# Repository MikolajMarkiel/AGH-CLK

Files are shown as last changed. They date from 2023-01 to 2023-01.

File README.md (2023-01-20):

# AGH-CLK
Tiny project of embedded wristwatch based on STM32 realised for University - course Design-Laboratory

## Project assumptions
The main goal was to make self-contained embedded wristwatch module that could be used with dedicated wrist as a complete wristwatch

## Technical specification
-	LCD screen 240x240 1,3 inches
-	Clock precision: -6 sec/day (would be better with capacitor corrections)
-	Current consumption: 54,5 mA (without sleep feature)
-	Estimated lifetime per cycle – around 9h (would be better with implemented sleep feature)
-	Charging: 5 VDC; 400 mA; around 75 minutes to full charge battery 500mAh 

## Overview
This project has been designed for purpose of learning STM32 programming and designing PCB with KiCad software. It won't be supported or improved in future. 
There are many mistakes such as huge current consumption, clock precision or aliased display. It could be of course improved for example by adding sleep feature, but it is not necessary to do right now, because others projects also wait to be designed. 

For more information about the project lets read AGH-CLK-Design_Process_Specification inside "Documentation" folder.

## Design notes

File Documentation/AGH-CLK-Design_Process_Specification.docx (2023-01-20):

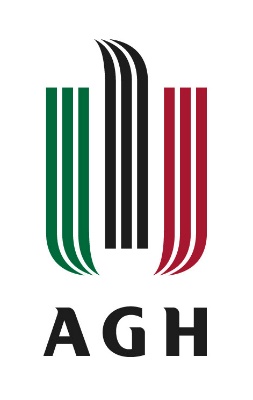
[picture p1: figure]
Wersje barwne znaku / Akademia Górniczo-Hutnicza w Krakowie

Design Laboratory

Project of Embedded wristwatch module powered by li-pol cell

AGH-CLK

Mateusz Bik, Mikołaj Markiel, Piotr Mosurek

20.01.2023

# Contents page

# 1. Design assumptions

## 1.1. Project description

The main goal was to make self-contained embedded wristwatch module that could be used with dedicated wrist as a complete wristwatch. That device has his own power supply made by li-pol cell with dedicated hardware driver. As a display full color LCD screen module is used with 240x240px and ST7789 driver. Device will be controlled by microprocessor STM32L051K6T6 that is placed on a dedicated printed circuit board “AGH-CLK-01” with the rest of peripherals.

## 1.2. Block diagram

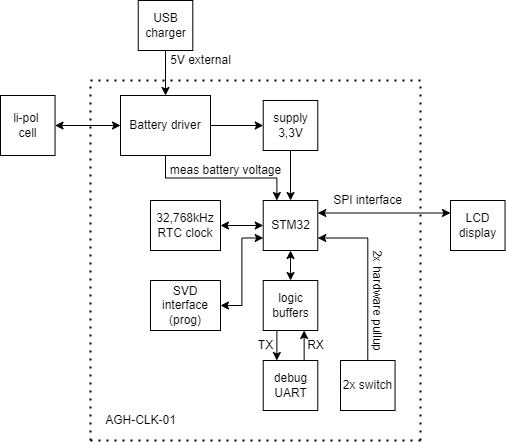
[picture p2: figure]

## 1.3. Technical specification:

- LCD screen 240x240 1,3 inches
- Clock precision: -6 sec/day (would be better with capacitor corrections)
- Current consumption: 54,5 mA (without sleep feature)
- Estimated lifetime per cycle – around 9h (would be better with implemented sleep feature)
- Charging: 5 VDC; 400 mA; around 75 minutes to full charge battery 500mAh

# 2. Schematic and layout descriptions

Schematic and layout was designed in KiCad Version: (6.0.9). PCB was prepared by JLCPCB company based on gerber files generated by KiCad.

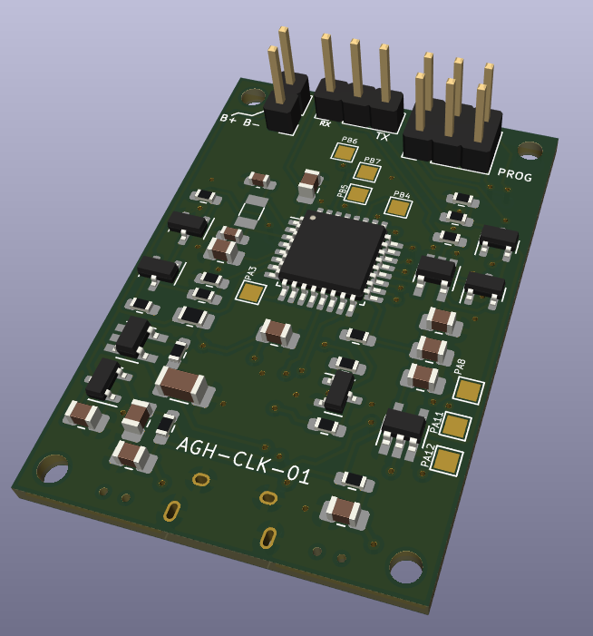
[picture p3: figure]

## 2.1. AGH-CLK-01 schematic

Full documentation is available in https://github.com/MikolajMarkiel/AGH-CLK

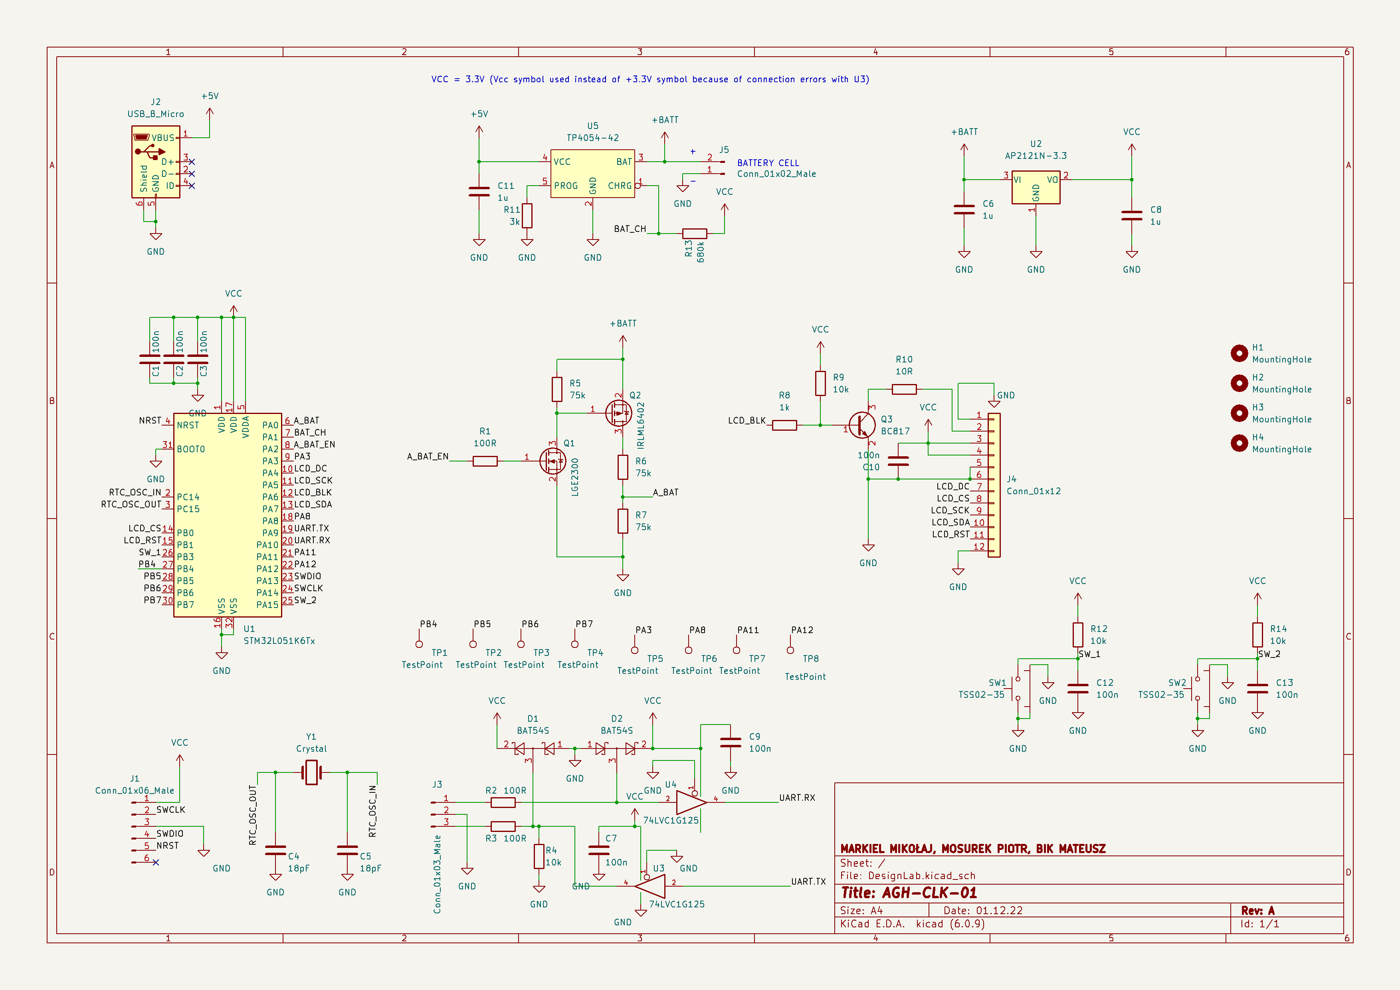
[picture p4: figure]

## 2.2. AGH-CLK-01 layout design

Full documentation is available in https://github.com/MikolajMarkiel/AGH-CLK

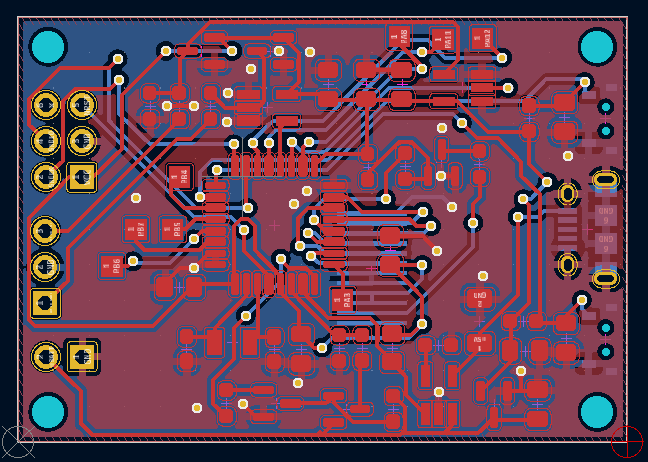
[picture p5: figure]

## 2.3. AGH-CLK-01 Bill of materials

Ref | Qnty | Value | Footprint | Description
C1, C2, C3, C7, C9, C10, C12, C13, | 8 | 100n | Capacitor_SMD:C_0805_2012Metric_Pad1.18x1.45mm_HandSolder | Unpolarized capacitor
C4, C5, | 2 | 18pF | Capacitor_SMD:C_0603_1608Metric_Pad1.08x0.95mm_HandSolder | Unpolarized capacitor
C6, C8, | 2 | 1u | Capacitor_SMD:C_0805_2012Metric_Pad1.18x1.45mm_HandSolder | Unpolarized capacitor
C11, | 1 | 1u | Capacitor_SMD:C_1206_3216Metric_Pad1.33x1.80mm_HandSolder | Unpolarized capacitor
D1, D2, | 2 | BAT54S | Package_TO_SOT_SMD:SOT-23 | schottky barrier diode
H1, H2, H3, H4, | 4 | MountingHole | MountingHole:MountingHole_2.2mm_M2_ISO7380 | Mounting Hole without connection
J1, | 1 | Conn_01x06_Male | Connector_PinHeader_2.54mm:PinHeader_2x03_P2.54mm_Vertical | Generic connector, single row, 01x06, script generated (kicad-library-utils/schlib/autogen/connector/)
J2, | 1 | USB_B_Micro | Connector_USB:USB_Micro-B_Amphenol_10118194_Horizontal | USB Micro Type B connector
J3, | 1 | Conn_01x03_Male | Connector_PinHeader_2.54mm:PinHeader_1x03_P2.54mm_Vertical | Generic connector, single row, 01x03, script generated (kicad-library-utils/schlib/autogen/connector/)
J4, | 1 | Conn_01x12 | Connector:Flex_Tape_12x0.635 | Generic connector, single row, 01x12, script generated (kicad-library-utils/schlib/autogen/connector/)
J5, | 1 | Conn_01x02_Male | Connector_PinHeader_2.54mm:PinHeader_1x02_P2.54mm_Vertical | Generic connector, single row, 01x02, script generated (kicad-library-utils/schlib/autogen/connector/)
Q1, | 1 | LGE2300 | Package_TO_SOT_SMD:SOT-23 | 1.2A Id, 60V Vds, 480mOhm Rds, N-Channel HEXFET Power MOSFET, SOT-23
Q2, | 1 | IRLML6402 | Package_TO_SOT_SMD:SOT-23 | -3.7A Id, -20V Vds, 65mOhm Rds, P-Channel HEXFET Power MOSFET, SOT-23
Q3, | 1 | BC817 | Package_TO_SOT_SMD:SOT-23 | 0.8A Ic, 45V Vce, NPN Transistor, SOT-23
R1, R2, R3, | 3 | 100R | Resistor_SMD:R_0603_1608Metric_Pad0.98x0.95mm_HandSolder | Resistor
R4, R9, R12, R14, | 4 | 10k | Resistor_SMD:R_0603_1608Metric_Pad0.98x0.95mm_HandSolder | Resistor
R5, R6, R7, | 3 | 75k | Resistor_SMD:R_0603_1608Metric_Pad0.98x0.95mm_HandSolder | Resistor
R8, | 1 | 1k | Resistor_SMD:R_0603_1608Metric_Pad0.98x0.95mm_HandSolder | Resistor
R10, | 1 | 10R | Resistor_SMD:R_0603_1608Metric_Pad0.98x0.95mm_HandSolder | Resistor
R11, | 1 | 3k | Resistor_SMD:R_0603_1608Metric_Pad0.98x0.95mm_HandSolder | Resistor
R13, | 1 | 680k | Resistor_SMD:R_0815_2038Metric_Pad1.20x4.05mm_HandSolder | Resistor
SW1, SW2, | 2 | TSS02-35 | Button_Switch_SMD:SW_SPST_TSS02-035NT | Push button switch, generic, two pins
TP1, TP2, TP3, TP4, TP5, TP6, TP7, TP8, | 8 | TestPoint | TestPoint:TestPoint_Pad_1.5x1.5mm | test point
U1, | 1 | STM32L051K6Tx | Package_QFP:LQFP-32_7x7mm_P0.8mm | ARM Cortex-M0+ MCU, 32KB flash, 8KB RAM, 32MHz, 1.65-3.6V, 25 GPIO, LQFP-32
U2, | 1 | AP2121N-3.3 | Package_TO_SOT_SMD:SOT-23 | 300mA low dropout linear regulator, shutdown pin, 2.5V-6V input voltage, 3.3V fixed positive output, SOT-23 package
U3, U4, | 2 | 74LVC1G125 | Package_TO_SOT_SMD:SOT-23-5_HandSoldering | Single Buffer Gate Tri-State, Low-Voltage CMOS
U5, | 1 | TP4054-42 | Package_TO_SOT_SMD:SOT-23-5_HandSoldering
Y1, | 1 | Crystal | Crystal:Crystal_SMD_3215-2Pin_3.2x1.5mm | Two pin crystal

## 2.4. Battery Driver block

For controlled battery charging TP4054-42 driver has been used. Maximum charging current of this driver is up to 1200mA. The particular value of the maximum current is configured by RPROG connected to PROG pin of driver The RPROG value is calculated by formula:

I_(BAT) =(V_(PROG))/(R_(PROG))*1200 (V_(PROG) =1V)

For purpose of this device assumed that the charging current should be around 400mA. The calculated RPROG value should be then no more than 3kΩ. The 3kΩ value has been chosen.

According to documentation weak pull-up should be used for checking battery charging state and connected to CHRG pin and to processor as input.

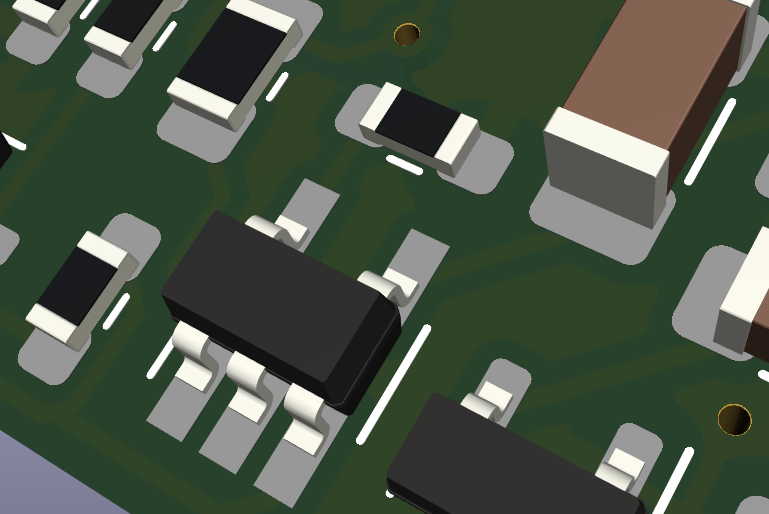
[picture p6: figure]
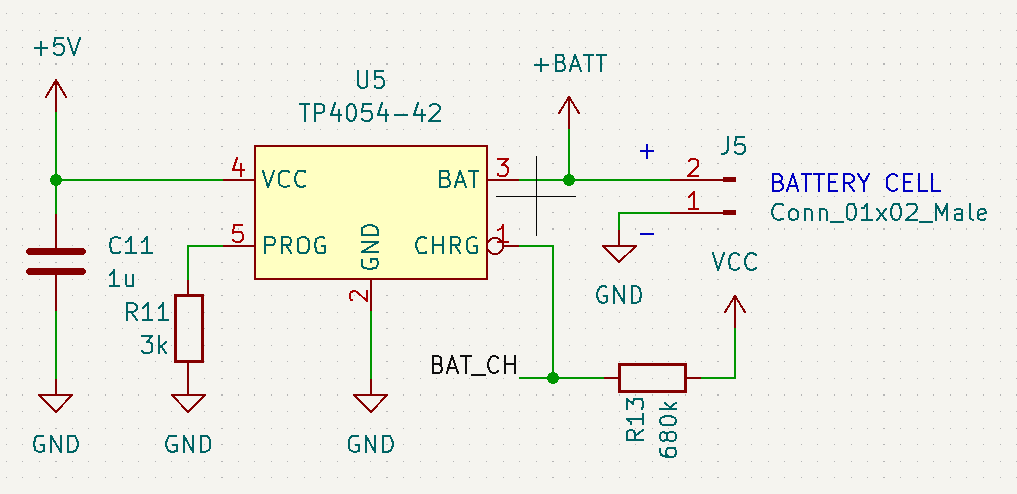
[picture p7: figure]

## 2.5. Power supply block

The voltage from battery is dropped to 3,3V for purpose of supplying processor and other peripherals. It is done by AP2127-3.3 linear voltage regulator. According to documentation this regulator has 2% accuracy, so the voltage should fit in 3,267-3,333V. The measured voltage is 3,291V, so the value is correct.

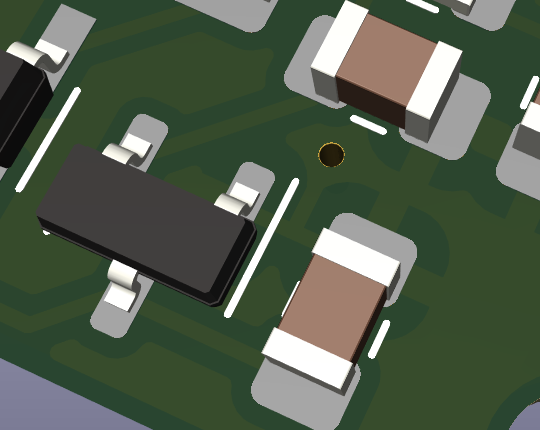
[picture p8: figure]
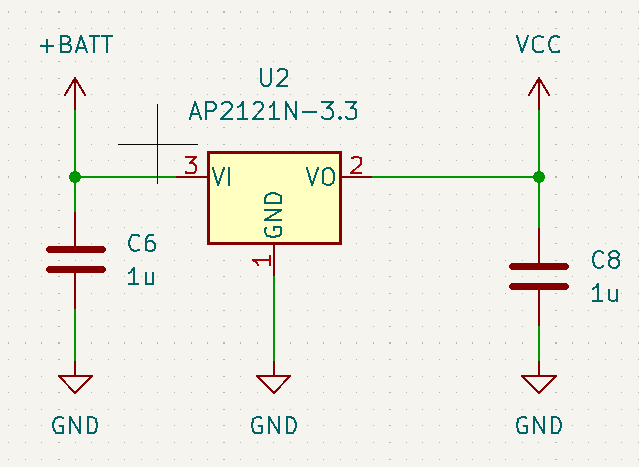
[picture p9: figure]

## 2.6. RTC clock

The STM32L051K6T6 supports external RTC crystal for precise counting. Because of that a ABS07-32.768KHZ-T crystal is used. It has 12.5pF load capacitance (CL). There is necessary to add extra capacitance for both terminals that aggregately should be equal to CL of crystal. We should also predict capacitance of copper paths for calculations (CSTRAY) (usually 2-5pF):

C_L =(C_(X1) *C_(X2))/(C_(X1) +C_(X2))+C_(STRAY)

We needed to use the same capacitor for this purpose, so the capacitance should then be in range 15-21pF. The correction of capacitance values of this circuit should be verified after assembly by checking clock precision.

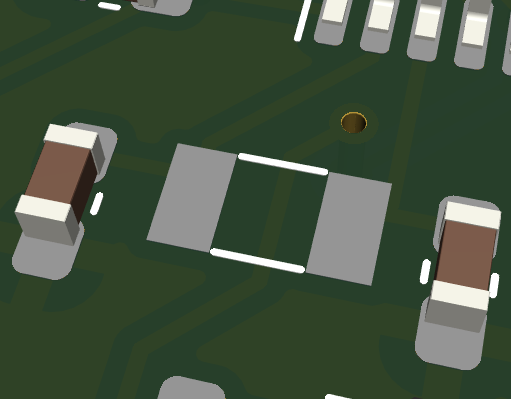
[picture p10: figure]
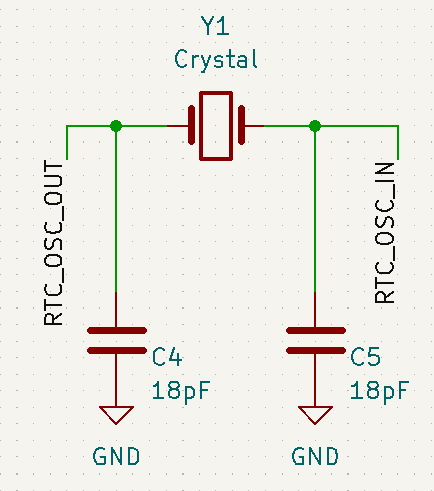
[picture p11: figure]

## 2.7. Processor and programming block

This project hasn’t had demanding requirements, so cheap STM32 processor would be enough to fulfil them all. We’ve decided to use STM32L051K6T6 processor. It has all necessary features and peripherals like SPI communication for LCD screen and RTC based on external clock.

To protect processor from unwanted resetting device we’ve placed 100nF decoupling capacitors near every power supply pin.

Programming will be realized by SWD interface. Unfortunately, this processor doesn’t have SWO pin, so real time debugging will be realized by UART.

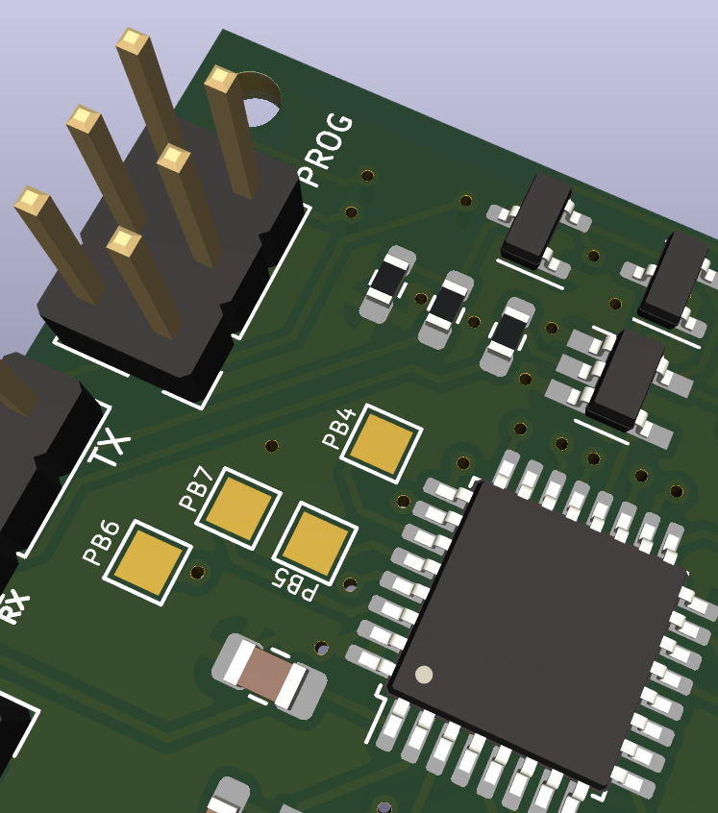
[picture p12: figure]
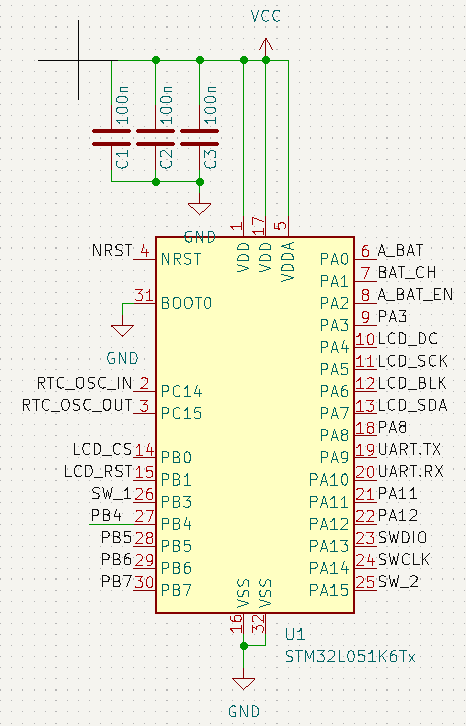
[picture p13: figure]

## 2.8. Debug Block

For real time debugging and testing UART communication has been carried to goldpin headers. To protect pins from dangerous signal RXD and TXD pins are buffered and protected from overvoltage.
Unfortunately this feature was not necessary to implement in software, and thus wasn’t tested.

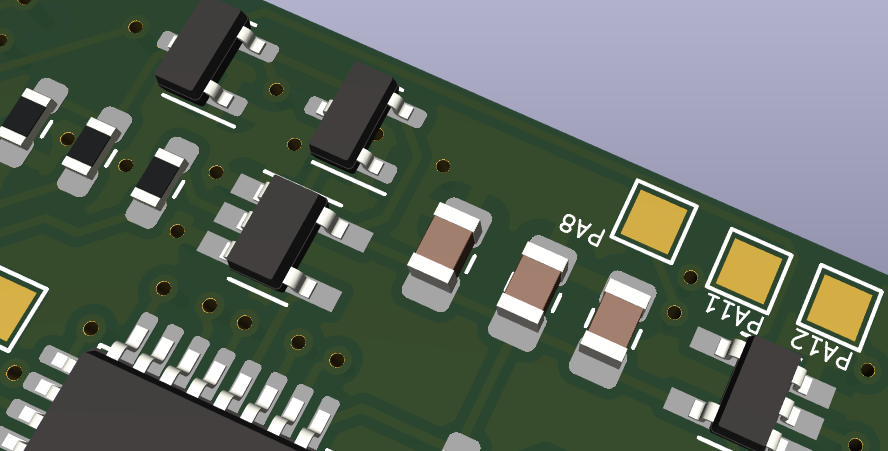
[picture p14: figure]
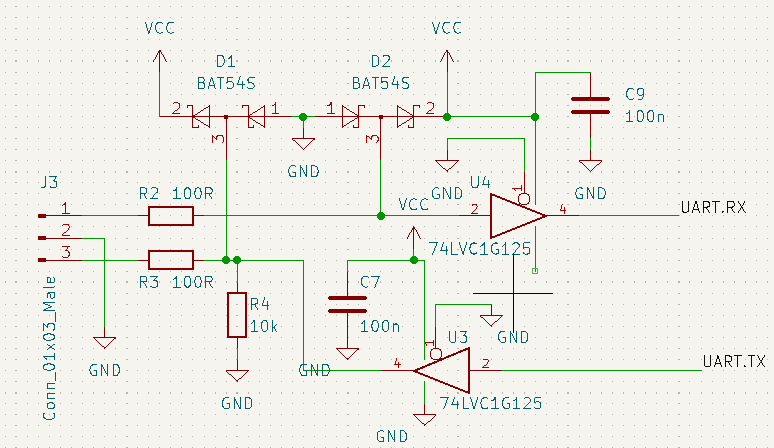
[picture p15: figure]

## 2.9. Keyboard

To control device, we’ve added two switches „<” and „>”. They will be used for setting actual time and date feature. To prevent from bouncing effect, we’ve used 100nF capacitor that filter unwanted noise:

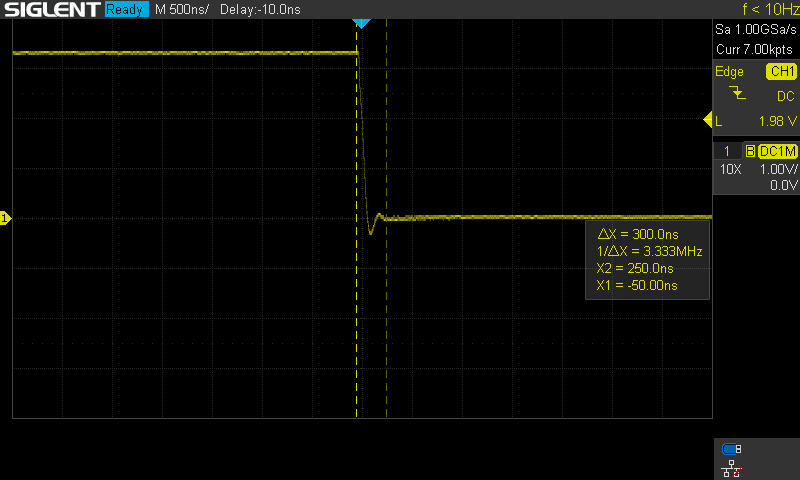
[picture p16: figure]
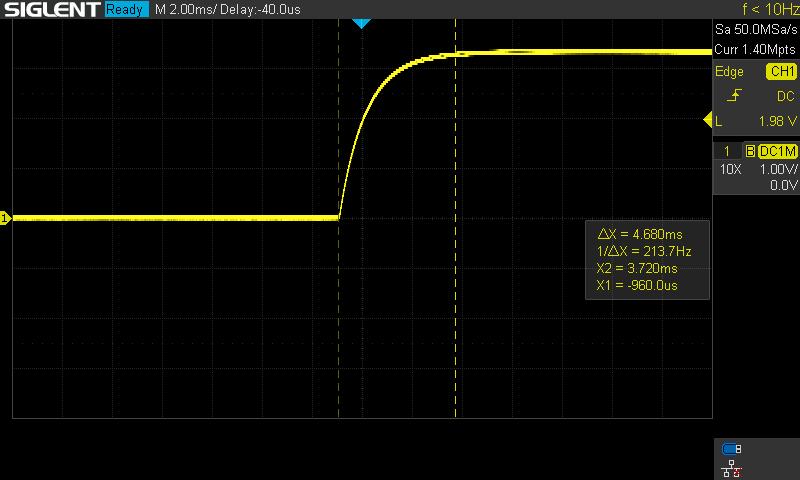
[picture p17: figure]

Figure 1: Removing bouncing effect from switches. At the left switch is pressed and pulled to ground, at the right switch is released and capacitor is charging again. The probe was connected directly to processor pin.

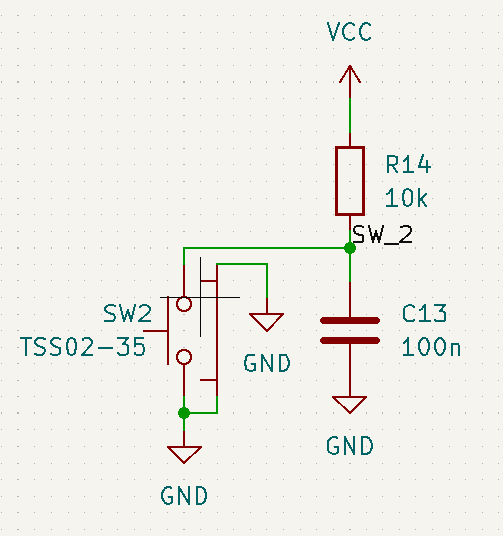
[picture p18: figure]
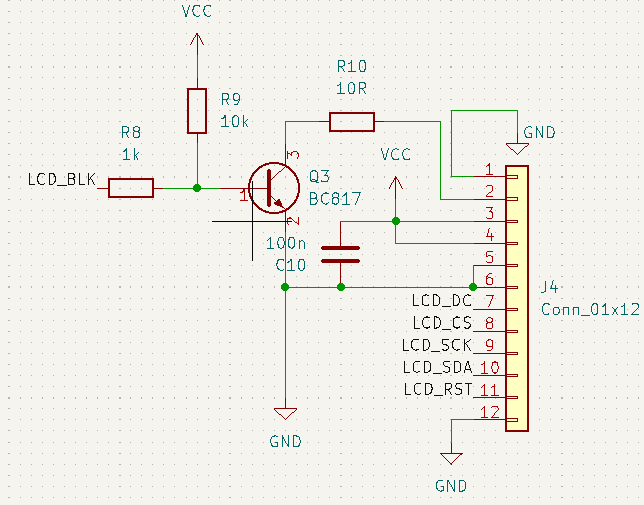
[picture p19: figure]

## 2.10. Display block

LCD screen display is communicating with processor via SPI half-duplex interface. The baud rate is 16 MBits/s. To unload processor from long transmission cycle data is transferred by DMA feature. There is also predicted possibility to control backlight of LCD screen.

# 3. Software description

## 3.1. Environment:

Software environment: STM32CubeIDE; Version: 1.10.1; Build: 12716_20220707_0928 (UTC)
Programmer: The ST-LINK/V2-1 programming and debugging tool integrated with NUCLEO-L476RG board

## 3.2. Code:

Full code is available in https://github.com/MikolajMarkiel/AGH-CLK

Libraries we’ve used in project:

- ST7789 driver with UGUI: https://github.com/deividAlfa/ST7789-STM32-uGUI

## 3.3. Performance algorithm

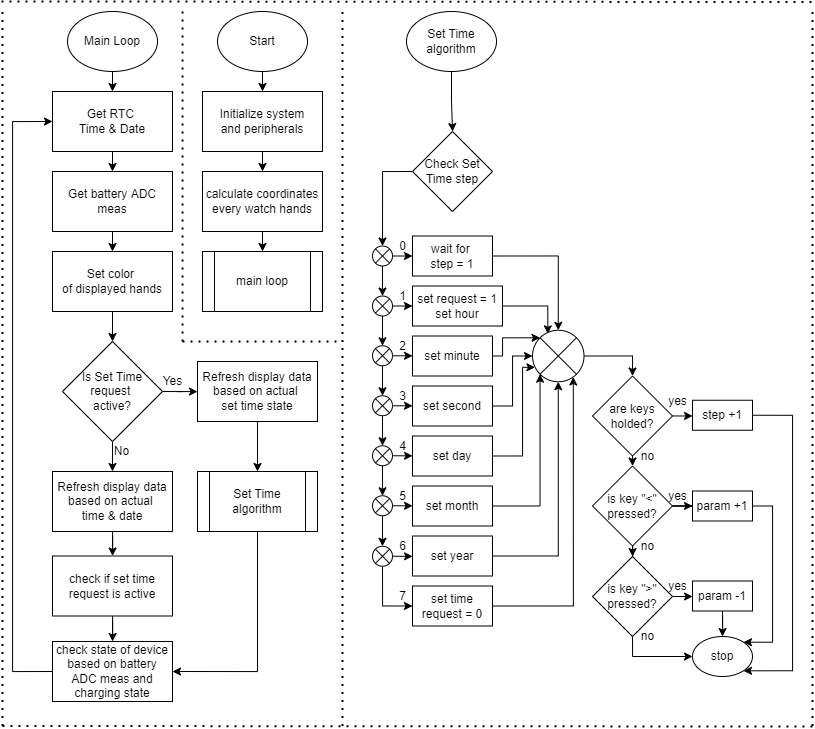
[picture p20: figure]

# 4. Performance tests

## 4.1. Battery performance

All tests were performed on a li-pol cell 2650mAh 3,7V.

Charging cycle:

Discharging cycle:

## 4.2. Clock precision

The test consist in synchronizing the clock and read its state after 24 hours. It was performed only once.

- Test 1: 18.01.23 18:50:00 – synchronize clock
- Test 2: 19.01.23 18:50:00 – read value 18:49:54 - 6s delay/day.

# 5. Future improvements and fixes

- Sleep feature – to decrease battery consumption and protect battery from over discharging.
- RTC capacitors update – for better clock precision.
- Touch pad – to allow controlling more features.
- UART-USB driver – to allow programming and debug via USB.
- Wristwatch case – to make this device wearable.

Version 1.020.01.2023Page 1 of 2

Design Laboratory AGH-CLK Project of Embedded wristwatch module powered by li-pol cell Opracował: Mikołaj Markiel, Mateusz Bik, Piotr Mosurek

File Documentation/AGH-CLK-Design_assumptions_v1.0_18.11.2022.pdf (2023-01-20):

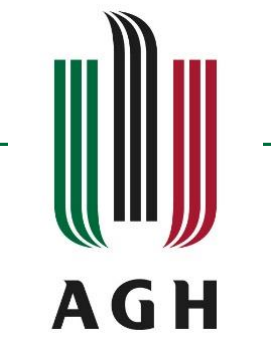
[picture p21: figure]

### Mateusz Bik, Mikołaj Markiel, Piotr Mosurek

18.11.2022

# Design Laboratory

# Project of Embedded wristwatch module powered by li-pol cell

## AGH-CLK

Design Laboratory | AGH-CLK
Project of Embedded wristwatch module powered by li-pol cell | Opracował: Mikołaj Markiel
Wersja 1.0 | 18.11.2022 | Strona 1 z 3

### Contents page


Wersja 1.0 | 18.11.2022 | Strona 2 z 3

### 1. Design assumptions

### 1.1. Project description

The main goal is to make self-contained embedded wristwatch module that could be used with dedicated wrist as a complete wristwatch. That device will have his own supply made by li-pol cell with dedicated hardware driver. As a display will be used full color LCD screen module with 240x240px and ST7789 driver. Device will be controlled by microprocessor STM32 (particular type will be pick in time) that would be placed on a dedicated printed circuit board “AGH-CLK-01” with the rest of peripherals. Everything should be assembled as a ready-to-use device.

### 1.2. Block diagram

### 1.3. Labour distribution

- Mateusz Bik:
- AGH-CLK-01 hardware schematic design
- Necessary schematic simulations
- Piotr Mosurek:
- AGH-CLK-01 hardware layout design
- Preparing bill of materials
- Collecting parts and device montage
- Mikołaj Markiel:
- AGH-CLK-01 software design
- Functional tests, debug and improvements

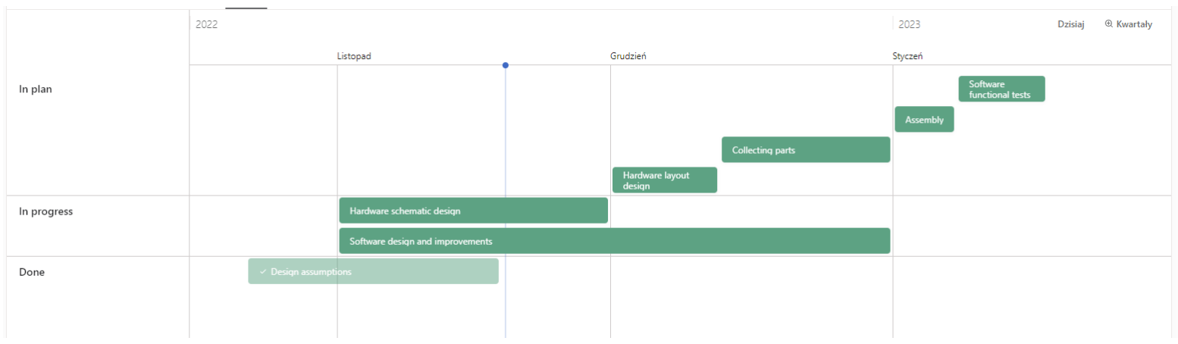
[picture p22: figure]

Wersja 1.0 | 18.11.2022 | Strona 3 z 3

### 2. Project schedule

Figure 1 Project schedule has been made in Asana

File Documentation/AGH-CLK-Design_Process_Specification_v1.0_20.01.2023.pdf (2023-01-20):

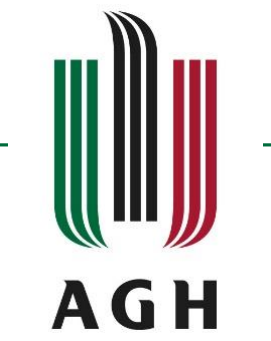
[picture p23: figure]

### Mateusz Bik, Mikołaj Markiel, Piotr Mosurek

# Design Laboratory

# Project of Embedded wristwatch module powered by li-pol cell

## AGH-CLK

Design Laboratory | AGH-CLK
Project of Embedded wristwatch module powered by li-pol cell | Opracował: Mikołaj Markiel, Mateusz Bik, Piotr Mosurek
Version 1.0 | 20.01.2023 | Page 1 of 11

20.01.2023

### Contents page

### 1. Design assumptions

### 1.1. Project description

The main goal was to make self-contained embedded wristwatch module that could be used with dedicated wrist as a complete wristwatch. That device has his own power supply made by li-pol cell with dedicated hardware driver. As a display full color LCD screen module is used with 240x240px and ST7789 driver. Device will be controlled by microprocessor STM32L051K6T6 that is placed on a dedicated printed circuit board “AGH-CLK-01” with the rest of peripherals.

### 1.2. Block diagram


### 1.3. Technical specification:

- LCD screen 240x240 1,3 inches
- Clock precision: -6 sec/day (would be better with capacitor corrections)
- Current consumption: 54,5 mA (without sleep feature)
- Estimated lifetime per cycle – around 9h (would be better with implemented sleep feature)
- Charging: 5 VDC; 400 mA; around 75 minutes to full charge battery 500mAh

### 2. Schematic and layout descriptions

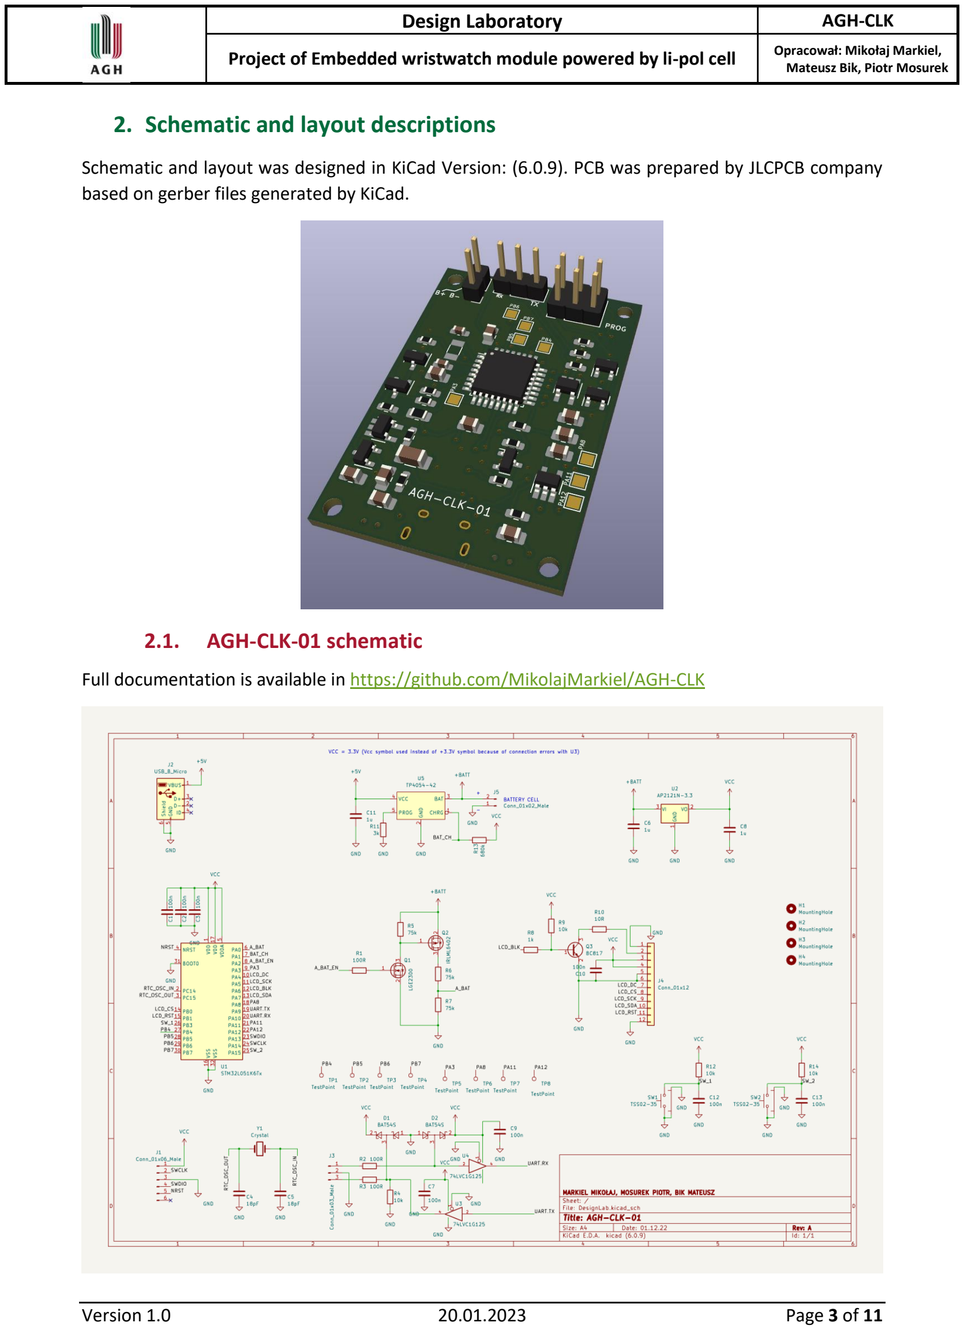
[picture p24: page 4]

Schematic and layout was designed in KiCad Version: (6.0.9). PCB was prepared by JLCPCB company based on gerber files generated by KiCad.

### 2.1. AGH-CLK-01 schematic

Full documentation is available in https://github.com/MikolajMarkiel/AGH-CLK

### 2.2. AGH-CLK-01 layout design

Full documentation is available in https://github.com/MikolajMarkiel/AGH-CLK


### 2.3. AGH-CLK-01 Bill of materials

Ref | Qnty | Value | Footprint | Description
C1, C2, C3, C7, C9, C10, C12, C13, | 8 | 100n | Capacitor_SMD:C_0805_2012Metric_Pad1.1 8x1.45mm_HandSolder | Unpolarized capacitor
C4, C5, | 2 | 18pF | Capacitor_SMD:C_0603_1608Metric_Pad1.0 8x0.95mm_HandSolder | Unpolarized capacitor
C6, C8, | 2 | 1u | Capacitor_SMD:C_0805_2012Metric_Pad1.1 8x1.45mm_HandSolder | Unpolarized capacitor
C11, | 1 | 1u | Capacitor_SMD:C_1206_3216Metric_Pad1.3 3x1.80mm_HandSolder | Unpolarized capacitor
D1, D2, | 2 | BAT54S | Package_TO_SOT_SMD:SOT-23 | schottky barrier diode
H1, H2, H3, H4, | 4 | MountingHole | MountingHole:MountingHole_2.2mm_M2_I SO7380 | Mounting Hole without connection
J1, | 1 | Conn_01x06_Male | Connector_PinHeader_2.54mm:PinHeader_ 2x03_P2.54mm_Vertical | Generic connector, single row, 01x06, script generated (kicad-library-utils/schlib/autogen/connector/)
J2, | 1 | USB_B_Micro | Connector_USB:USB_Micro-B_Amphenol_10118194_Horizontal | USB Micro Type B connector
J3, | 1 | Conn_01x03_Male | Connector_PinHeader_2.54mm:PinHeader_ 1x03_P2.54mm_Vertical | Generic connector, single row, 01x03, script generated (kicad-library-utils/schlib/autogen/connector/)
J4, | 1 | Conn_01x12 | Connector:Flex_Tape_12x0.635 | Generic connector, single row, 01x12, script generated (kicad-library-utils/schlib/autogen/connector/)
J5, | 1 | Conn_01x02_Male | Connector_PinHeader_2.54mm:PinHeader_ 1x02_P2.54mm_Vertical | Generic connector, single row, 01x02, script generated (kicad-library-utils/schlib/autogen/connector/)
Q1, | 1 | LGE2300 | Package_TO_SOT_SMD:SOT-23 | 1.2A Id, 60V Vds, 480mOhm Rds, N-Channel HEXFET Power MOSFET, SOT-23
Q2, | 1 | IRLML6402 | Package_TO_SOT_SMD:SOT-23 | -3.7A Id, -20V Vds, 65mOhm Rds, P-Channel HEXFET Power MOSFET, SOT-23
Q3, | 1 | BC817 | Package_TO_SOT_SMD:SOT-23 | 0.8A Ic, 45V Vce, NPN Transistor, SOT-23

R1, R2, R3, | 3 | 100R | Resistor_SMD:R_0603_1608Metric_Pad0.98 x0.95mm_HandSolder | Resistor
R4, R9, R12, R14, | 4 | 10k | Resistor_SMD:R_0603_1608Metric_Pad0.98 x0.95mm_HandSolder | Resistor
R5, R6, R7, | 3 | 75k | Resistor_SMD:R_0603_1608Metric_Pad0.98 x0.95mm_HandSolder | Resistor
R8, | 1 | 1k | Resistor_SMD:R_0603_1608Metric_Pad0.98 x0.95mm_HandSolder | Resistor
R10, | 1 | 10R | Resistor_SMD:R_0603_1608Metric_Pad0.98 x0.95mm_HandSolder | Resistor
R11, | 1 | 3k | Resistor_SMD:R_0603_1608Metric_Pad0.98 x0.95mm_HandSolder | Resistor
R13, | 1 | 680k | Resistor_SMD:R_0815_2038Metric_Pad1.20 x4.05mm_HandSolder | Resistor
SW1, SW2, | 2 | TSS02-35 | Button_Switch_SMD:SW_SPST_TSS02-035NT | Push button switch, generic, two pins
TP1, TP2, TP3, TP4, TP5, TP6, TP7, TP8, | 8 | TestPoint | TestPoint:TestPoint_Pad_1.5x1.5mm | test point
U1, | 1 | STM32L051K6Tx | Package_QFP:LQFP-32_7x7mm_P0.8mm | ARM Cortex-M0+ MCU, 32KB flash, 8KB RAM, 32MHz, 1.65-3.6V, 25 GPIO, LQFP-32
U2, | 1 | AP2121N-3.3 | Package_TO_SOT_SMD:SOT-23 | 300mA low dropout linear regulator, shutdown pin, 2.5V-6V input voltage, 3.3V fixed positive output, SOT-23 package
U3, U4, | 2 | 74LVC1G125 | Package_TO_SOT_SMD:SOT-23-5_HandSoldering | Single Buffer Gate Tri-State, Low-Voltage CMOS
U5, | 1 | TP4054-42 | Package_TO_SOT_SMD:SOT-23-5_HandSoldering
Y1, | 1 | Crystal | Crystal:Crystal_SMD_3215-2Pin_3.2x1.5mm | Two pin crystal

### 2.4. Battery Driver block

For controlled battery charging TP4054-42 driver has been used. Maximum charging current of this driver is up to 1200mA. The particular value of the maximum current is configured by RPROG connected to PROG pin of driver The RPROG value is calculated by formula:

IBAT =

VPROG

RPROG

∗ 1200 (VPROG = 1V)

For purpose of this device assumed that the charging current should be around 400mA. The calculated RPROG value should be then no more than 3kΩ. The 3kΩ value has been chosen.

According to documentation weak pull-up should be used for checking battery charging state and connected to CHRG pin and to processor as input.


### 2.5. Power supply block

The voltage from battery is dropped to 3,3V for purpose of supplying processor and other peripherals. It is done by AP2127-3.3 linear voltage regulator. According to documentation this regulator has 2% accuracy, so the voltage should fit in 3,267-3,333V. The measured voltage is 3,291V, so the value is correct.


### 2.6. RTC clock

The STM32L051K6T6 supports external RTC crystal for precise counting. Because of that a ABS07-32.768KHZ-T crystal is used. It has 12.5pF load capacitance (CL). There is necessary to add extra capacitance for both terminals that aggregately should be equal to CL of crystal. We should also predict capacitance of copper paths for calculations (CSTRAY) (usually 2-5pF):

CL =

CX1 ∗ CX2

CX1 + CX2

+ CSTRAY

We needed to use the same capacitor for this purpose, so the capacitance should then be in range 15-21pF. The correction of capacitance values of this circuit should be verified after assembly by checking clock precision.


### 2.7. Processor and programming block

This project hasn’t had demanding requirements, so cheap STM32 processor would be enough to fulfil them all. We’ve decided to use STM32L051K6T6 processor. It has all necessary features and peripherals like SPI communication for LCD screen and RTC based on external clock.

To protect processor from unwanted resetting device we’ve placed 100nF decoupling capacitors near every power supply pin.

Programming will be realized by SWD interface. Unfortunately, this processor doesn’t have SWO pin, so real time debugging will be realized by UART.


### 2.8. Debug Block

For real time debugging and testing UART communication has been carried to goldpin headers. To protect pins from dangerous signal RXD and TXD pins are buffered and protected from overvoltage. Unfortunately this feature was not necessary to implement in software, and thus wasn’t tested.


### 2.9. Keyboard

To control device, we’ve added two switches „<” and „>”. They will be used for setting actual time and date feature. To prevent from bouncing effect, we’ve used 100nF capacitor that filter unwanted noise:


Figure 1: Removing bouncing effect from switches. At the left switch is pressed and pulled to ground, at the right switch is released and capacitor is charging again. The probe was connected directly to processor pin.


### 2.10. Display block


LCD screen display is communicating with processor via SPI half-duplex interface. The baud rate is 16 MBits/s. To unload processor from long transmission cycle data is transferred by DMA feature. There is also predicted possibility to control backlight of LCD screen.

### 3. Software description

### 3.1. Environment:

Software environment: STM32CubeIDE; Version: 1.10.1; Build: 12716_20220707_0928 (UTC) Programmer: The ST-LINK/V2-1 programming and debugging tool integrated with NUCLEO-L476RG board

### 3.2. Code:

Full code is available in https://github.com/MikolajMarkiel/AGH-CLK

Libraries we’ve used in project:

- ST7789 driver with UGUI: https://github.com/deividAlfa/ST7789-STM32-uGUI

### 3.3. Performance algorithm


### 4. Performance tests

### Voltage rise during charging cycle

4.1. Battery performance; Charging cycle:; Discharging cycle:

All tests were performed on a li-pol cell 2650mAh 3,7V.

Battery voltage drop during discharging cycle

### 4.2. Clock precision

The test consist in synchronizing the clock and read its state after 24 hours. It was performed only once.

- Test 1: 18.01.23 18:50:00 – synchronize clock
- Test 2: 19.01.23 18:50:00 – read value 18:49:54 - 6s delay/day.

### 5. Future improvements and fixes

- Sleep feature – to decrease battery consumption and protect battery from over discharging.
- RTC capacitors update – for better clock precision.
- Touch pad – to allow controlling more features.
- UART-USB driver – to allow programming and debug via USB.
- Wristwatch case – to make this device wearable.

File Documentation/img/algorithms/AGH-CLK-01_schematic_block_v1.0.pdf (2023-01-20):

STM32; Battery driver; supply; USB charger; li-pol cell; LCD display; debug UART; 2x switch; 32,768kHz RTC clock; 5V external; meas battery voltage; SPI interface 2x hardware pullup; logic buffers; AGH-CLK-01; SVD interface (prog)

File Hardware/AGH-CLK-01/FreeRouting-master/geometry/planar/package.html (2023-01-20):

Contains general purpose 2-dimensional geometry classes.

## Some preliminary considerations on computational geometry:

What is better in arithmetic calculations? Using floating-point or fixed-point arithmetic? In floating-point arithmetic we can forget about absolute exactness. There is for example no way to find out if three points are exactly collinear in floating-point arithmetic. In fixed-point arithmetic however there is an easy way to calculate for any line, if a point is on the left, on the right, or exact on this line. That exactness is the main reason to prefer fixed-point (integer) arithmetic to floating-point arithmetic in computational geometry.

With integer arithmetic we get no problems in calculations with orthogonal lines, and some limited problems with 45-degree lines. With any-angle lines however there is a problem. Between the start point and the end point of a line segment there may not exist a single integer point exact on the line. Also the intersection of two lines can in general not be represented exactly by an integer point.

Can we get exactness in calculations with shapes defined by integer points in spite of this?

Suppose we represent polygon shapes by its corner points. The intersection of two polygon shapes is then represented by a subset of the corners of the two polygons and the intersections of its boundary line segments. But these line intersections can in general not be represented by integer points. If we round them to integer points, the result will not be exact.

But we can do better. We can represent shapes by its boundary lines instead of its corner points. The intersection of two shapes is then described by a subset of the boundary lines of the shapes. The only work to do is skipping boundary lines that do not contribute to the result. But because we have not calculated any new geometrical objects, the result of this calculation remains exact.

Similar problems exist with polygons for example. Therefore we will not represent them by a sequence of corner points, but by a sequence of lines with integer coordinates.

Although our key concern will be on fixed-point (integer) arithmetic, we will also use some floating-point and infinite precision rational number arithmetic in our geometry system.

## General Programming Principles used in the code:

### Principle 1: Immutability

An object is called immutable, if its content will never change after it is constructed. In this prototype all objects are created immutable, if there is no good reason to do otherwise. In a language with a garbage collector there never arises the need to copy an immutable object. Instead just another reference to the object can be added. That is safe because nobody else is allowed to change the object. The garbage collector recycles the object automatically, when there is no more reference to it. Immutable objects also have no synchronisation problems, in case they are accessed by several threads simultaneously.

Having objects in geometry immutable lets them look much more like they are used in school or university mathematics. You do not expect in mathematics for example, that the coordinates of a point will change later on.

### Principle 2: Abstract Data Types

Object variables should be of abstract classes, if possible. Concrete classes should only be used in the creation of objects, that is on the right side of the ‘new’ keyword or in a so-called factory method. That makes it easy to exchange and mix several implementations of an abstract class. The user has no access to the actual implementation, but only to the abstract functions every implementation must provide. There is one major problem. The virtual function mechanism does not work in parameter position. This means that the appropriate concrete class will not be found automatically, if an abstract class is provided in parameter position. Adding for such functions a private helper function for each concrete implementation of the abstract class solves the problem, as long as the function has no more than one abstract parameter. This solution still looks reasonable. Until now I could always avoid the need for functions to have more than one abstract parameter. Functions with many parameters may be bad designed anyway.

### Description of the package:

This packages contains the implementation of 2-dimensional geometric objects such as points, vectors, lines, shapes, and so on.

The abstract class Point for example defines the behaviour, which must be implemented by each concrete Point class. There are two concrete implementations of the class Point at the moment, the class IntPoint, which implements the Point as a tuple of integer values, and the class RationalPoint. The class RationalPoint implements infinite precision integer points in the projective plane. This is a generalisation of an implementation of infinite precision rational points in the affine plane. With RationalPoints for example the intersection of two lines can always be calculated exactly. The usage of these two classes is mixed and RationalPoints will always be converted to IntPoints if possible, to improve the performance.

Strongly related to the class Point is the class Vector. A Vector can be added to a Point resulting in another Point. A Point can be subtracted from another Point resulting in a Vector. Of course two vectors can be added resulting in another vector. For every vector v there exists the negative vector v.negate () so that v + v.negate () is the zero vector.

Instead of angles we use Directions in our geometry system. The reason is that for a Line (to be defined later) its Direction can be represented exactly while its angle can be not. The best we can do with angles is to approximate them by floating point numbers. But in this case there exists for example no exact algorithm to determine if two angles are equal. A Direction is defined as an equivalence class of Vectors. Two vectors define the same Direction, if they point into the same direction.

Directions are ordered in the following way. A Direction d1 is bigger than a Direction d2, if it has a bigger angle with the positive X-axis. We can compare the size of 2 Directions by calculating the determinant of their defining vectors. This calculation is exact in integer arithmetic.

An object of the class Line is defined as an infinite directed line. In addition to an ordinary infinite line a directed line defines a positive and a negative half-plane. The positive half-plane is to the left of the line, and the negative half-plane to the right. Such a Line is represented by a tuple of abstract points (a, b) on the line, which are assumed to be not equal. The positive half-plane is the set of points p, so that a path from a to b to p makes a left turn. Of course two different tuples of points can define the same line.

The class FloatPoint is used in arithmetic calculations, where execution speed is more important than numerical accuracy. The class Line for example contains the two methods: “intersection” and “intersection_approx”. Both of them calculate the intersection of two lines. The function “intersection” returns an object of the abstract class Point. The result is exact, but the calculation may be slow, because it uses infinite precision arithmetic.

The function “intersection_approx” uses double precision floating point arithmetic to calculate an object of the class FloatPoint. This calculation is quite fast, but the result of floating point arithmetic is not exact in general.

Because all calculations in the abstract class Point are expected to be exact, FloatPoint is not derived from the abstract class Point, as IntPoint and RationalPoint are.

In the following section we describe the class hierarchy describing shapes in the plane. The root of the hierarchy is the interface Area. It defines functionality of of connected 2-dimensional sets of points in the plane, which need not necessarily to be simply connected. (For non mathematicians that means an Area may have holes.) Derived from the Interface Area is the interface Shape, which defines functionality for simply connected areas (areas without holes). Derived from the interface Shape are the Interface ConvexShape and the abstract class PolylineShape. A shape is convex, if for any 2 points a, b inside the shape the line segment from a to b is contained completely in the shape. A PolylineShape is defined as a shape, whose border consists of a sequence of straight lines. Derived from PolylineShape is the class PolygonShape. A PolygonShape is a PolylineShape represented by a closed polygon of corner points. From ConvexShape the class Circle and the abstract class TileShape are derived. TileShape is also derived from PolylineShape, There are currently 3 implementations of the class TileShape : IntBox, IntOctagon and Simplex. IntBoxes are axis parallel rectangles with int coordinates, IntOctagons are convex shapes, whose boundary line angles are multiples of 45 degree,

A Simplex is implemented as a finite set of lines. The shape of a Simplex is defined as the intersection of all positive half-planes of its lines. Simplexes are similar to convex polygons defined by a finite set of corner points. The difference is that a Simplex may contain infinite parts. A half-plane for example is a Simplex, but not a convex polygon. In an Integer geometry system using Simplexes instead of convex polygons has many advantages. Assume for example that we want to calculate the intersection of two polygons. For this purpose we have to calculate the intersections of the crossing edge lines. These intersections are in general no longer integer points. This means, that the intersection of two convex polygons can not be represented exactly by a convex polygon with integer coordinates. We could use RationalPoints for the corners to achieve this goal, but then the arithmetic calculations would get very slow. Calculating the intersection of two Simplexes is quite different. We just take the sum of the defining lines of the two Simplexes. The real work is skipping the lines, which do not contribute to the result. So the intersection of two Simplexes calculated in this way is exact, even if our lines have integer coordinates. A RegularTileShape is a TileShape, where the directions of the boundary lines may only be from a fixed finite set. IntBoxes and IntOctagons are RegularTileShape´s, but Simplexes are not.

In the class Polyline curves in the plane consisting of a list of straight lines are described. No two consecutive lines in that list may be parallel. Therefore a Polyline of n lines with integer coordinates is equivalent to a polygon of n – 1 RationalPoints, where the k-th RationalPoint is the intersection of the k-th and the k+1-th line for 0 <= k < n –1 (if we disregard the possibility of integer overflow). We will use the class Polyline especially to describe Traces on a Printed Circuit Board. That enables us to implement a numerical stable any-angle pushing algorithm for traces. The reason is similar as for Simplexes. We do not use intersection points of lines to create the geometry of new trace objects in the pushing algorithm. Instead we use lines, which already exist, for that purpose. That concept is also advantageous when we want to smoothen traces by cutting of corners. If this is done with polygons represented by corners, the intersection of lines has to be calculated and used as primary data. If integer points are used, these intersection points are not exact. Neighbour lines change slightly and a small clearance violation may occur. If rational points are used, the algorithm gets very slow. With Polylines these problems do not exist, because intersection points of lines never become primary data.

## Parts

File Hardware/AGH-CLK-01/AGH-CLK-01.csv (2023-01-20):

Source: | D:\Projekty\AGH-CLK-01\Hardware\Nowy folder\AGH-CLK-01\AGH-CLK-01.kicad_sch
Date: | 1/20/2023 9:15:52 PM
Tool: | Eeschema (6.0.9)
Generator: | D:\Programy\Zainstalowane\KiCad\6.0\bin\scripting\plugins/bom_csv_grouped_by_value_with_fp.py
Component Count: | 57
Ref | Qnty | Value | Cmp name | Footprint | Description | Vendor
C1, C2, C3, C7, C9, C10, C12, C13, | 8 | 100n | C | Capacitor_SMD:C_0805_2012Metric_Pad1.18x1.45mm_HandSolder | Unpolarized capacitor
C4, C5, | 2 | 18pF | C | Capacitor_SMD:C_0603_1608Metric_Pad1.08x0.95mm_HandSolder | Unpolarized capacitor
C6, C8, | 2 | 1u | C | Capacitor_SMD:C_0805_2012Metric_Pad1.18x1.45mm_HandSolder | Unpolarized capacitor
C11, | 1 | 1u | C | Capacitor_SMD:C_1206_3216Metric_Pad1.33x1.80mm_HandSolder | Unpolarized capacitor
D1, D2, | 2 | BAT54S | BAT54S | Package_TO_SOT_SMD:SOT-23 | schottky barrier diode
H1, H2, H3, H4, | 4 | MountingHole | MountingHole | MountingHole:MountingHole_2.2mm_M2_ISO7380 | Mounting Hole without connection
J1, | 1 | Conn_01x06_Male | Conn_01x06_Male | Connector_PinHeader_2.54mm:PinHeader_2x03_P2.54mm_Vertical | Generic connector, single row, 01x06, script generated (kicad-library-utils/schlib/autogen/connector/)
J2, | 1 | USB_B_Micro | USB_B_Micro | Connector_USB:USB_Micro-B_Amphenol_10118194_Horizontal | USB Micro Type B connector
J3, | 1 | Conn_01x03_Male | Conn_01x03_Male | Connector_PinHeader_2.54mm:PinHeader_1x03_P2.54mm_Vertical | Generic connector, single row, 01x03, script generated (kicad-library-utils/schlib/autogen/connector/)
J4, | 1 | Conn_01x12 | Conn_01x12 | Connector:Flex_Tape_12x0.635 | Generic connector, single row, 01x12, script generated (kicad-library-utils/schlib/autogen/connector/)
J5, | 1 | Conn_01x02_Male | Conn_01x02_Male | Connector_PinHeader_2.54mm:PinHeader_1x02_P2.54mm_Vertical | Generic connector, single row, 01x02, script generated (kicad-library-utils/schlib/autogen/connector/)
Q1, | 1 | LGE2300 | IRLML2060 | Package_TO_SOT_SMD:SOT-23 | 1.2A Id, 60V Vds, 480mOhm Rds, N-Channel HEXFET Power MOSFET, SOT-23
Q2, | 1 | IRLML6402 | IRLML6402 | Package_TO_SOT_SMD:SOT-23 | -3.7A Id, -20V Vds, 65mOhm Rds, P-Channel HEXFET Power MOSFET, SOT-23
Q3, | 1 | BC817 | BC817 | Package_TO_SOT_SMD:SOT-23 | 0.8A Ic, 45V Vce, NPN Transistor, SOT-23
R1, R2, R3, | 3 | 100R | R | Resistor_SMD:R_0603_1608Metric_Pad0.98x0.95mm_HandSolder | Resistor
R4, R9, R12, R14, | 4 | 10k | R | Resistor_SMD:R_0603_1608Metric_Pad0.98x0.95mm_HandSolder | Resistor
R5, R6, R7, | 3 | 75k | R | Resistor_SMD:R_0603_1608Metric_Pad0.98x0.95mm_HandSolder | Resistor
R8, | 1 | 1k | R | Resistor_SMD:R_0603_1608Metric_Pad0.98x0.95mm_HandSolder | Resistor
R10, | 1 | 10R | R | Resistor_SMD:R_0603_1608Metric_Pad0.98x0.95mm_HandSolder | Resistor
R11, | 1 | 3k | R | Resistor_SMD:R_0603_1608Metric_Pad0.98x0.95mm_HandSolder | Resistor
R13, | 1 | 680k | R | Resistor_SMD:R_0805_2012Metric_Pad1.20x1.40mm_HandSolder | Resistor
SW1, SW2, | 2 | TSS02-35 | SW_Push_GND | Button_Switch_SMD:SW_SPST_TSS02-035NT | Push button switch, generic, two pins
TP1, TP2, TP3, TP4, TP5, TP6, TP7, TP8, | 8 | TestPoint | TestPoint | TestPoint:TestPoint_Pad_1.5x1.5mm | test point
U1, | 1 | STM32L051K6Tx | STM32L051K6Tx | Package_QFP:LQFP-32_7x7mm_P0.8mm | ARM Cortex-M0+ MCU, 32KB flash, 8KB RAM, 32MHz, 1.65-3.6V, 25 GPIO, LQFP-32
U2, | 1 | AP2121N-3.3 | AP2127N-3.3 | Package_TO_SOT_SMD:SOT-23 | 300mA low dropout linear regulator, shutdown pin, 2.5V-6V input voltage, 3.3V fixed positive output, SOT-23 package
U3, U4, | 2 | 74LVC1G125 | 74LVC1G125 | Package_TO_SOT_SMD:SOT-23-5_HandSoldering | Single Buffer Gate Tri-State, Low-Voltage CMOS
U5, | 1 | TP4054-42 | TP4054-42 | Package_TO_SOT_SMD:SOT-23-5_HandSoldering
Y1, | 1 | Crystal | Crystal | Crystal:Crystal_SMD_3215-2Pin_3.2x1.5mm | Two pin crystal

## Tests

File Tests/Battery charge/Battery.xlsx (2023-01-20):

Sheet: Charge
Time | Voltage
0:00:00 | 3.823
0:00:15 | 3.841
0:00:30 | 3.842
0:00:45 | 3.843
0:01:00 | 3.844
0:01:15 | 3.844
0:01:30 | 3.845
0:01:45 | 3.844
0:02:00 | 3.846
0:02:15 | 3.847
0:02:30 | 3.847
0:02:45 | 3.847
0:03:00 | 3.848
0:03:15 | 3.848
0:03:30 | 3.849
0:03:45 | 3.848
0:04:00 | 3.848
0:04:15 | 3.850
0:04:30 | 3.849
0:04:45 | 3.849
0:05:00 | 3.850
0:05:15 | 3.851
0:05:30 | 3.851
0:05:45 | 3.851
0:06:00 | 3.851
0:06:15 | 3.852
0:06:30 | 3.851
0:06:45 | 3.852
0:07:00 | 3.852
0:07:15 | 3.853
0:07:30 | 3.853
0:07:45 | 3.853
0:08:00 | 3.853
0:08:15 | 3.854
0:08:30 | 3.854
0:08:45 | 3.855
0:09:00 | 3.855
0:09:15 | 3.855
0:09:30 | 3.855
0:09:45 | 3.856
0:10:00 | 3.856
0:10:15 | 3.856
0:10:30 | 3.856
0:10:45 | 3.856
0:11:00 | 3.858
0:11:15 | 3.858
0:11:30 | 3.857
0:11:45 | 3.857
0:12:00 | 3.858
0:12:15 | 3.858
0:12:30 | 3.859
0:12:45 | 3.858
0:13:00 | 3.859
0:13:15 | 3.859
0:13:30 | 3.859
0:13:45 | 3.860
0:14:00 | 3.860
0:14:15 | 3.861
0:14:30 | 3.860
0:14:45 | 3.862
0:15:00 | 3.861
0:15:15 | 3.861
0:15:30 | 3.862
0:15:45 | 3.863
0:16:00 | 3.862
0:16:15 | 3.863
0:16:30 | 3.863
0:16:45 | 3.863
0:17:00 | 3.864
0:17:15 | 3.863
0:17:30 | 3.863
0:17:45 | 3.864
0:18:00 | 3.864
0:18:15 | 3.865
0:18:30 | 3.865
0:18:45 | 3.865
0:19:00 | 3.866
0:19:15 | 3.865
0:19:30 | 3.866
0:19:45 | 3.866
0:20:00 | 3.867
0:20:15 | 3.867
0:20:30 | 3.867
0:20:45 | 3.867
0:21:00 | 3.867
0:21:15 | 3.867
0:21:30 | 3.867
0:21:45 | 3.868
0:22:00 | 3.868
0:22:15 | 3.869
0:22:30 | 3.869
0:22:45 | 3.869
0:23:00 | 3.869
0:23:15 | 3.869
0:23:30 | 3.870
0:23:45 | 3.870
0:24:00 | 3.870
0:24:15 | 3.870
0:24:30 | 3.870
0:24:45 | 3.871
0:25:00 | 3.871
0:25:15 | 3.871
0:25:30 | 3.871
0:25:45 | 3.872
0:26:00 | 3.872
0:26:15 | 3.871
0:26:30 | 3.872
0:26:45 | 3.872
0:27:00 | 3.873
0:27:15 | 3.872
0:27:30 | 3.873
0:27:45 | 3.873
0:28:00 | 3.874
0:28:15 | 3.873
0:28:30 | 3.874
0:28:45 | 3.874
0:29:00 | 3.874
0:29:15 | 3.875
0:29:30 | 3.875
0:29:45 | 3.875
0:30:00 | 3.875
0:30:15 | 3.875
0:30:30 | 3.875
0:30:45 | 3.876
0:31:00 | 3.876
0:31:15 | 3.876
0:31:30 | 3.877
0:31:45 | 3.877
0:32:00 | 3.876
0:32:15 | 3.877
0:32:30 | 3.877
0:32:45 | 3.878
0:33:00 | 3.878
0:33:15 | 3.878
0:33:30 | 3.879
0:33:45 | 3.879
0:34:00 | 3.879
0:34:15 | 3.879
0:34:30 | 3.879
0:34:45 | 3.880
0:35:00 | 3.879
0:35:15 | 3.880
0:35:30 | 3.879
0:35:45 | 3.880
0:36:00 | 3.880
0:36:15 | 3.881
0:36:30 | 3.881
0:36:45 | 3.881
0:37:00 | 3.881
0:37:15 | 3.881
0:37:30 | 3.881
0:37:45 | 3.881
0:38:00 | 3.883
0:38:15 | 3.882
0:38:30 | 3.883
0:38:45 | 3.883
0:39:00 | 3.883
0:39:15 | 3.883
0:39:30 | 3.883
0:39:45 | 3.884
0:40:00 | 3.884
0:40:15 | 3.884
0:40:30 | 3.884
0:40:45 | 3.884
0:41:00 | 3.885
0:41:15 | 3.885
0:41:30 | 3.885
0:41:45 | 3.886
0:42:00 | 3.886
0:42:15 | 3.886
0:42:30 | 3.886
0:42:45 | 3.886
0:43:00 | 3.887
0:43:15 | 3.887
0:43:30 | 3.886
0:43:45 | 3.887
0:44:00 | 3.887
0:44:15 | 3.888
0:44:30 | 3.887
0:44:45 | 3.888
0:45:00 | 3.888
0:45:15 | 3.888
0:45:30 | 3.888
0:45:45 | 3.888
0:46:00 | 3.889
0:46:15 | 3.889
0:46:30 | 3.889
0:46:45 | 3.890
0:47:00 | 3.890
0:47:15 | 3.890
0:47:30 | 3.890
0:47:45 | 3.890
0:48:00 | 3.890
0:48:15 | 3.890
0:48:30 | 3.890
0:48:45 | 3.891
0:49:00 | 3.891
0:49:15 | 3.891
0:49:30 | 3.892
0:49:45 | 3.892
0:50:00 | 3.892
0:50:15 | 3.892
0:50:30 | 3.893
0:50:45 | 3.892
0:51:00 | 3.893
0:51:15 | 3.892
0:51:30 | 3.893
0:51:45 | 3.894
0:52:00 | 3.893
0:52:15 | 3.894
0:52:30 | 3.894
0:52:45 | 3.894
0:53:00 | 3.894
0:53:15 | 3.894
0:53:30 | 3.895
0:53:45 | 3.895
0:54:00 | 3.895
0:54:15 | 3.895
0:54:30 | 3.895
0:54:45 | 3.896
0:55:00 | 3.895
0:55:15 | 3.895
0:55:30 | 3.896
0:55:45 | 3.896
0:56:00 | 3.896
0:56:15 | 3.897
0:56:30 | 3.896
0:56:45 | 3.897
0:57:00 | 3.897
0:57:15 | 3.897
0:57:30 | 3.897
0:57:45 | 3.898
0:58:00 | 3.898
0:58:15 | 3.898
0:58:30 | 3.898
0:58:45 | 3.898
0:59:00 | 3.899
0:59:15 | 3.899
0:59:30 | 3.899
0:59:45 | 3.899
1:00:00 | 3.898
1:00:15 | 3.900
1:00:30 | 3.900
1:00:45 | 3.899
1:01:00 | 3.900
1:01:15 | 3.899
1:01:30 | 3.900
1:01:45 | 3.900
1:02:00 | 3.900
1:02:15 | 3.901
1:02:30 | 3.901
1:02:45 | 3.901
1:03:00 | 3.902
1:03:15 | 3.901
1:03:30 | 3.902
1:03:45 | 3.901
1:04:00 | 3.902
1:04:15 | 3.902
1:04:30 | 3.901
1:04:45 | 3.902
1:05:00 | 3.902
1:05:15 | 3.902
1:05:30 | 3.902
1:05:45 | 3.903
1:06:00 | 3.903
1:06:15 | 3.903
1:06:30 | 3.903
1:06:45 | 3.903
1:07:00 | 3.903
1:07:15 | 3.904
1:07:30 | 3.903
1:07:45 | 3.904
1:08:00 | 3.904
1:08:15 | 3.904
1:08:30 | 3.905
1:08:45 | 3.905
1:09:00 | 3.904
1:09:15 | 3.904
1:09:30 | 3.905
1:09:45 | 3.905
1:10:00 | 3.905
1:10:15 | 3.905
1:10:30 | 3.906
1:10:45 | 3.905
1:11:00 | 3.906
1:11:15 | 3.906
1:11:30 | 3.906
1:11:45 | 3.906
1:12:00 | 3.906
1:12:15 | 3.907
1:12:30 | 3.906
1:12:45 | 3.907
1:13:00 | 3.907
1:13:15 | 3.907
1:13:30 | 3.907
1:13:45 | 3.908
1:14:00 | 3.907
1:14:15 | 3.908
1:14:30 | 3.907
1:14:45 | 3.908
1:15:00 | 3.908
1:15:15 | 3.908
1:15:30 | 3.908
1:15:45 | 3.909
1:16:00 | 3.909
1:16:15 | 3.909
1:16:30 | 3.909
1:16:45 | 3.909
1:17:00 | 3.910
1:17:15 | 3.910
1:17:30 | 3.910
1:17:45 | 3.910
1:18:00 | 3.910
1:18:15 | 3.910
1:18:30 | 3.911
1:18:45 | 3.911
1:19:00 | 3.911
1:19:15 | 3.912
1:19:30 | 3.911
1:19:45 | 3.912
1:20:00 | 3.913
1:20:15 | 3.912
1:20:30 | 3.911
1:20:45 | 3.911
1:21:00 | 3.912
1:21:15 | 3.913
1:21:30 | 3.912
1:21:45 | 3.912
1:22:00 | 3.913
1:22:15 | 3.913
1:22:30 | 3.913
1:22:45 | 3.913
1:23:00 | 3.913
1:23:15 | 3.914
1:23:30 | 3.914
1:23:45 | 3.914
1:24:00 | 3.914
1:24:15 | 3.914
1:24:30 | 3.914
1:24:45 | 3.914
1:25:00 | 3.915
1:25:15 | 3.915
1:25:30 | 3.915
1:25:45 | 3.916
1:26:00 | 3.915
1:26:15 | 3.915
1:26:30 | 3.916
1:26:45 | 3.916
1:27:00 | 3.916
1:27:15 | 3.916
1:27:30 | 3.916
1:27:45 | 3.916
1:28:00 | 3.917
1:28:15 | 3.918
1:28:30 | 3.917
1:28:45 | 3.917
1:29:00 | 3.917
1:29:15 | 3.918
1:29:30 | 3.918
1:29:45 | 3.918
1:30:00 | 3.918
1:30:15 | 3.918
1:30:30 | 3.918
1:30:45 | 3.919
1:31:00 | 3.918
1:31:15 | 3.918
1:31:30 | 3.919
1:31:45 | 3.919
1:32:00 | 3.919
1:32:15 | 3.919
1:32:30 | 3.920
1:32:45 | 3.920
1:33:00 | 3.920
1:33:15 | 3.920
1:33:30 | 3.920
1:33:45 | 3.920
1:34:00 | 3.920
1:34:15 | 3.921
1:34:30 | 3.920
1:34:45 | 3.921
1:35:00 | 3.921
1:35:15 | 3.921
1:35:30 | 3.922
1:35:45 | 3.922
1:36:00 | 3.922
1:36:15 | 3.922
1:36:30 | 3.922
1:36:45 | 3.922
1:37:00 | 3.922
1:37:15 | 3.924
1:37:30 | 3.923
1:37:45 | 3.923
1:38:00 | 3.923
1:38:15 | 3.924
1:38:30 | 3.923
1:38:45 | 3.923
1:39:00 | 3.923
1:39:15 | 3.924
1:39:30 | 3.924
1:39:45 | 3.924
1:40:00 | 3.924
1:40:15 | 3.924
1:40:30 | 3.925
1:40:45 | 3.925
1:41:00 | 3.925
1:41:15 | 3.925
1:41:30 | 3.926
1:41:45 | 3.925
1:42:00 | 3.925
1:42:15 | 3.925
1:42:30 | 3.925
1:42:45 | 3.926
1:43:00 | 3.925
1:43:15 | 3.926
1:43:30 | 3.926
1:43:45 | 3.926
1:44:00 | 3.926
1:44:15 | 3.926
1:44:30 | 3.926
1:44:45 | 3.927
1:45:00 | 3.927
1:45:15 | 3.927
1:45:30 | 3.927
1:45:45 | 3.927
1:46:00 | 3.927
1:46:15 | 3.928
1:46:30 | 3.928
1:46:45 | 3.927
1:47:00 | 3.928
1:47:15 | 3.928
1:47:30 | 3.928
1:47:45 | 3.928
1:48:00 | 3.928
1:48:15 | 3.929
1:48:30 | 3.929
1:48:45 | 3.928
1:49:00 | 3.928
1:49:15 | 3.929
1:49:30 | 3.928
1:49:45 | 3.929
1:50:00 | 3.929
1:50:15 | 3.929
1:50:30 | 3.929
1:50:45 | 3.929
1:51:00 | 3.929
1:51:15 | 3.929
1:51:30 | 3.930
1:51:45 | 3.929
1:52:00 | 3.929
1:52:15 | 3.930
1:52:30 | 3.929
1:52:45 | 3.930
1:53:00 | 3.930
1:53:15 | 3.930
1:53:30 | 3.930
1:53:45 | 3.930
1:54:00 | 3.930
1:54:15 | 3.930
1:54:30 | 3.931
1:54:45 | 3.930
1:55:00 | 3.930
1:55:15 | 3.931
1:55:30 | 3.931
1:55:45 | 3.930
1:56:00 | 3.931
1:56:15 | 3.931
1:56:30 | 3.931
1:56:45 | 3.931
1:57:00 | 3.932
1:57:15 | 3.932
1:57:30 | 3.932
1:57:45 | 3.932
1:58:00 | 3.932
1:58:15 | 3.932
1:58:30 | 3.932
1:58:45 | 3.932
1:59:00 | 3.932
1:59:15 | 3.933
1:59:30 | 3.932
1:59:45 | 3.932
2:00:00 | 3.933
2:00:15 | 3.933
2:00:30 | 3.933
2:00:45 | 3.932
2:01:00 | 3.932
2:01:15 | 3.933
2:01:30 | 3.933
2:01:45 | 3.933
2:02:00 | 3.933
2:02:15 | 3.933
2:02:30 | 3.933
2:02:45 | 3.933
2:03:00 | 3.933
2:03:15 | 3.934
2:03:30 | 3.934
2:03:45 | 3.933
2:04:00 | 3.933
2:04:15 | 3.934
2:04:30 | 3.934
2:04:45 | 3.934
2:05:00 | 3.934
2:05:15 | 3.934
2:05:30 | 3.934
2:05:45 | 3.934
2:06:00 | 3.934
2:06:15 | 3.934
2:06:30 | 3.934
2:06:45 | 3.934
2:07:00 | 3.934
2:07:15 | 3.934
2:07:30 | 3.934
2:07:45 | 3.934
2:08:00 | 3.934
2:08:15 | 3.934
2:08:30 | 3.935
2:08:45 | 3.935
2:09:00 | 3.934
2:09:15 | 3.935
2:09:30 | 3.935
2:09:45 | 3.935
2:10:00 | 3.935
2:10:15 | 3.936
2:10:30 | 3.936
2:10:45 | 3.935
2:11:00 | 3.935
2:11:15 | 3.935
2:11:30 | 3.936
2:11:45 | 3.935
2:12:00 | 3.936
2:12:15 | 3.936
2:12:30 | 3.935
2:12:45 | 3.935
2:13:00 | 3.935
2:13:15 | 3.936
2:13:30 | 3.936
2:13:45 | 3.936
2:14:00 | 3.936
2:14:15 | 3.936
2:14:30 | 3.936
2:14:45 | 3.936
2:15:00 | 3.936
2:15:15 | 3.936
2:15:30 | 3.936
2:15:45 | 3.936
2:16:00 | 3.936
2:16:15 | 3.936
2:16:30 | 3.936
2:16:45 | 3.937
2:17:00 | 3.936
2:17:15 | 3.937
2:17:30 | 3.937
2:17:45 | 3.937
2:18:00 | 3.937
2:18:15 | 3.936
2:18:30 | 3.937
2:18:45 | 3.937
2:19:00 | 3.937
2:19:15 | 3.937
2:19:30 | 3.937
2:19:45 | 3.937
2:20:00 | 3.937
2:20:15 | 3.938
2:20:30 | 3.937
2:20:45 | 3.938
2:21:00 | 3.938
2:21:15 | 3.938
2:21:30 | 3.938
2:21:45 | 3.937
2:22:00 | 3.938
2:22:15 | 3.938
2:22:30 | 3.938
2:22:45 | 3.938
2:23:00 | 3.938
2:23:15 | 3.938
2:23:30 | 3.938
2:23:45 | 3.938
2:24:00 | 3.939
2:24:15 | 3.938
2:24:30 | 3.938
2:24:45 | 3.939
2:25:00 | 3.939
2:25:15 | 3.938
2:25:30 | 3.939
2:25:45 | 3.939
2:26:00 | 3.938
2:26:15 | 3.939
2:26:30 | 3.939
2:26:45 | 3.939
2:27:00 | 3.938
2:27:15 | 3.938
2:27:30 | 3.940
2:27:45 | 3.938
2:28:00 | 3.940
2:28:15 | 3.939
2:28:30 | 3.939
2:28:45 | 3.939
2:29:00 | 3.939
2:29:15 | 3.939
2:29:30 | 3.939
2:29:45 | 3.939
2:30:00 | 3.939
2:30:15 | 3.939
2:30:30 | 3.939
2:30:45 | 3.939
2:31:00 | 3.939
2:31:15 | 3.939
2:31:30 | 3.940
2:31:45 | 3.940
2:32:00 | 3.940
2:32:15 | 3.940
2:32:30 | 3.939
2:32:45 | 3.939
2:33:00 | 3.939
2:33:15 | 3.940
2:33:30 | 3.939
2:33:45 | 3.940
2:34:00 | 3.940
2:34:15 | 3.940
2:34:30 | 3.940
2:34:45 | 3.941
2:35:00 | 3.940
2:35:15 | 3.940
2:35:30 | 3.940
2:35:45 | 3.941
2:36:00 | 3.940
2:36:15 | 3.940
2:36:30 | 3.940
2:36:45 | 3.941
2:37:00 | 3.941
2:37:15 | 3.941
2:37:30 | 3.941
2:37:45 | 3.941
2:38:00 | 3.941
2:38:15 | 3.941
2:38:30 | 3.941
2:38:45 | 3.941
2:39:00 | 3.940
2:39:15 | 3.941
2:39:30 | 3.941
2:39:45 | 3.941
2:40:00 | 3.941
2:40:15 | 3.941
2:40:30 | 3.941
2:40:45 | 3.941
2:41:00 | 3.941
2:41:15 | 3.941
2:41:30 | 3.941
2:41:45 | 3.941
2:42:00 | 3.941
2:42:15 | 3.942
2:42:30 | 3.941
2:42:45 | 3.941
2:43:00 | 3.942
2:43:15 | 3.942
2:43:30 | 3.942
2:43:45 | 3.942
2:44:00 | 3.942
2:44:15 | 3.942
2:44:30 | 3.942
2:44:45 | 3.942
2:45:00 | 3.942
2:45:15 | 3.942
2:45:30 | 3.942
2:45:45 | 3.943
2:46:00 | 3.943
2:46:15 | 3.943
2:46:30 | 3.943
2:46:45 | 3.942
2:47:00 | 3.942
2:47:15 | 3.943
2:47:30 | 3.943
2:47:45 | 3.943
2:48:00 | 3.943
2:48:15 | 3.942
2:48:30 | 3.943
2:48:45 | 3.943
2:49:00 | 3.942
2:49:15 | 3.943
2:49:30 | 3.943
2:49:45 | 3.943
2:50:00 | 3.942
2:50:15 | 3.943
2:50:30 | 3.943
2:50:45 | 3.943
2:51:00 | 3.943
2:51:15 | 3.943
2:51:30 | 3.944
2:51:45 | 3.943
2:52:00 | 3.943
2:52:15 | 3.943
2:52:30 | 3.944
2:52:45 | 3.943
2:53:00 | 3.943
2:53:15 | 3.944
2:53:30 | 3.944
2:53:45 | 3.944
2:54:00 | 3.944
2:54:15 | 3.943
2:54:30 | 3.944
2:54:45 | 3.944
2:55:00 | 3.944
2:55:15 | 3.944
2:55:30 | 3.944
2:55:45 | 3.945
2:56:00 | 3.944
2:56:15 | 3.944
2:56:30 | 3.944
2:56:45 | 3.944
2:57:00 | 3.943
2:57:15 | 3.945
2:57:30 | 3.944
2:57:45 | 3.945
2:58:00 | 3.945
2:58:15 | 3.944
2:58:30 | 3.945
2:58:45 | 3.945
2:59:00 | 3.945
2:59:15 | 3.944
2:59:30 | 3.944
2:59:45 | 3.945
3:00:00 | 3.945
3:00:15 | 3.945
3:00:30 | 3.945
3:00:45 | 3.945
3:01:00 | 3.946
3:01:15 | 3.945
3:01:30 | 3.945
3:01:45 | 3.946
3:02:00 | 3.946
3:02:15 | 3.945
3:02:30 | 3.945
3:02:45 | 3.945
3:03:00 | 3.946
3:03:15 | 3.945
3:03:30 | 3.946
3:03:45 | 3.945
3:04:00 | 3.945
3:04:15 | 3.947
3:04:30 | 3.946
3:04:45 | 3.946
3:05:00 | 3.946
3:05:15 | 3.946
3:05:30 | 3.946
3:05:45 | 3.945
3:06:00 | 3.946
3:06:15 | 3.946
3:06:30 | 3.947
3:06:45 | 3.946
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

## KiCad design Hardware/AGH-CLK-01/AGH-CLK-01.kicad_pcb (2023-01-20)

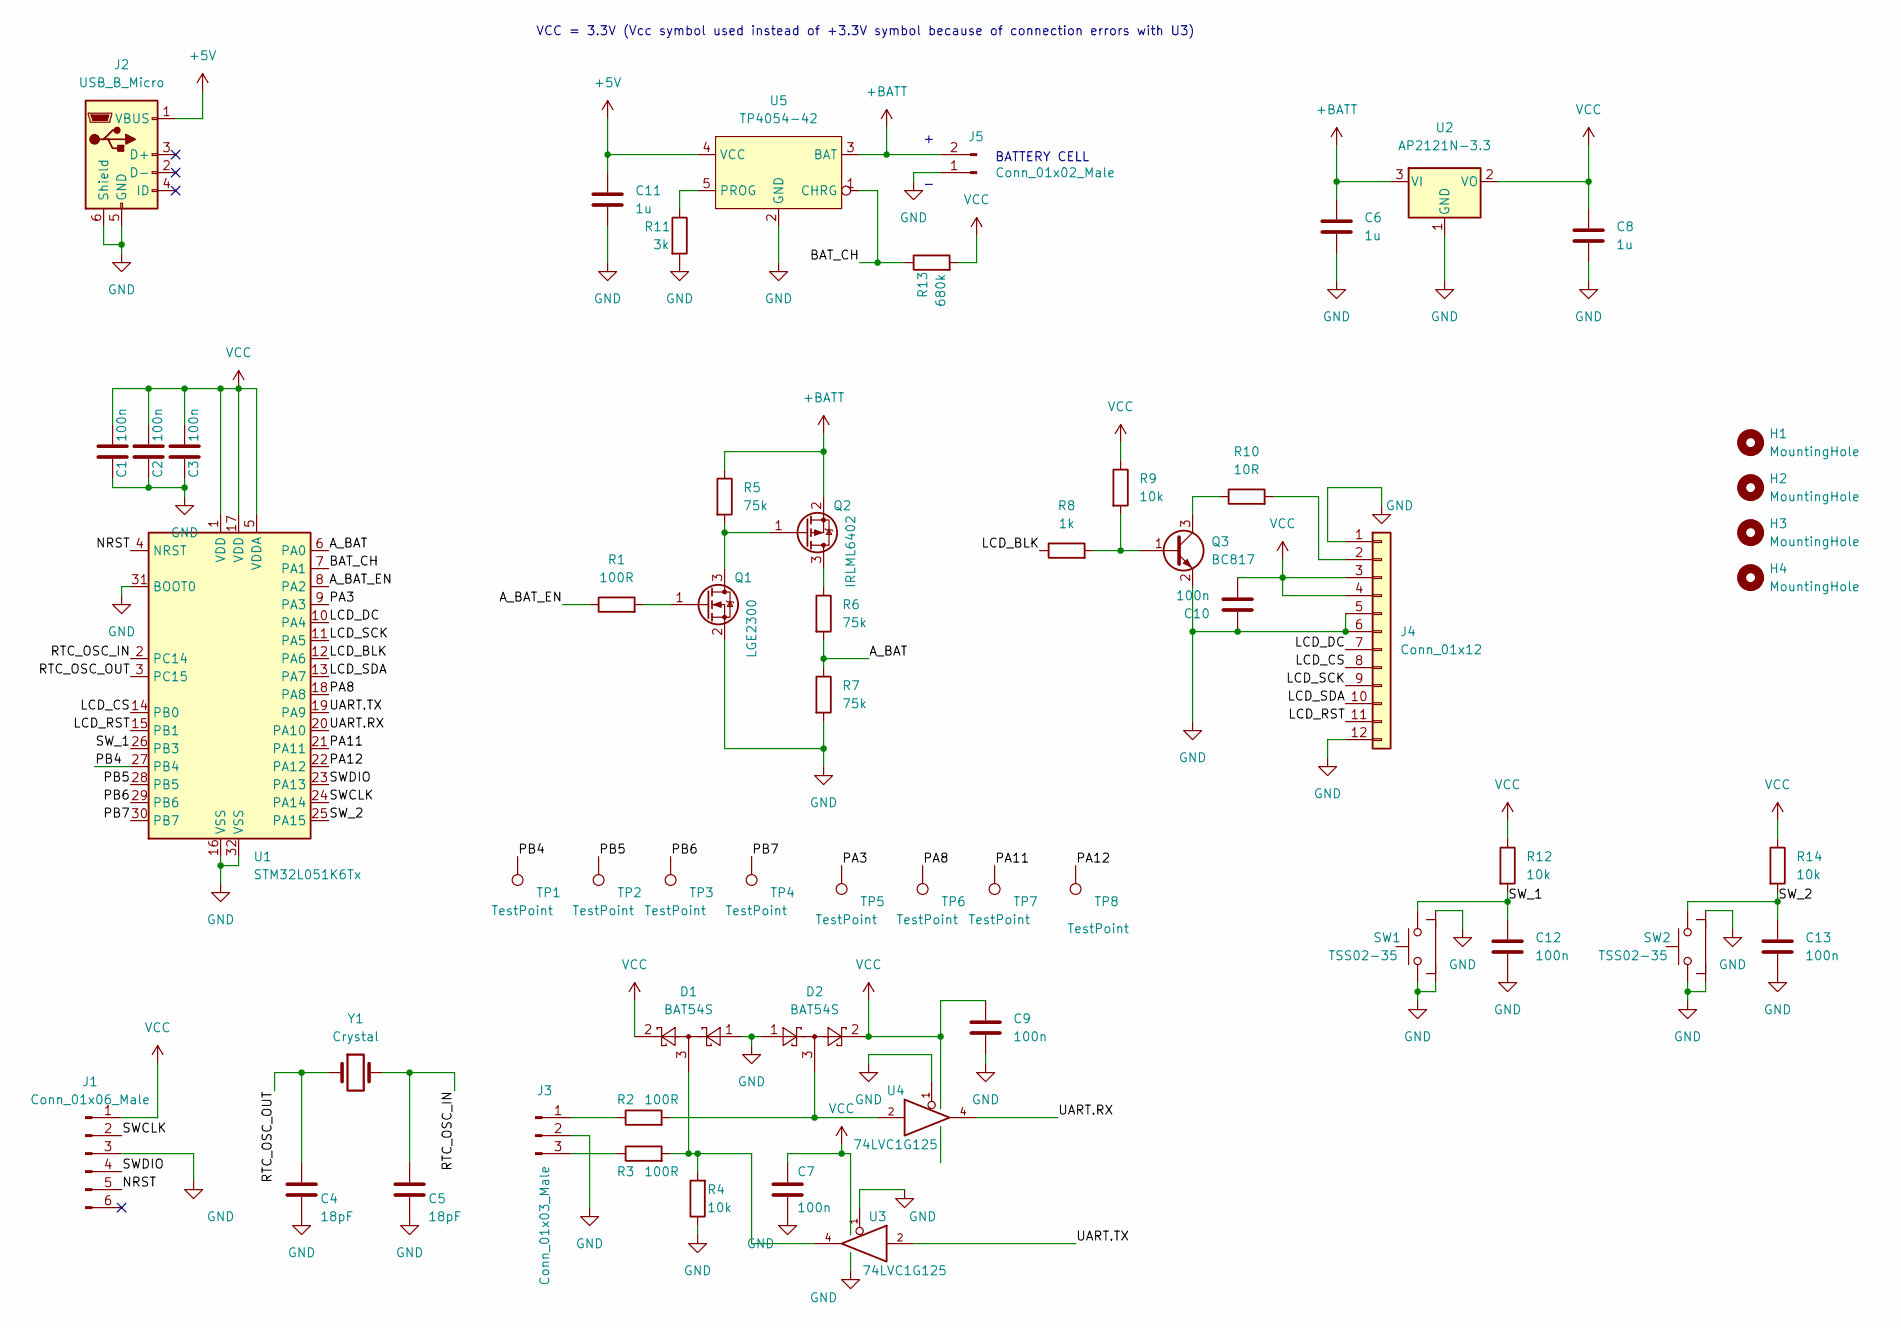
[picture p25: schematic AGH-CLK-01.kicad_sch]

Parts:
C1, C2, C3, C7, C9, C10, C12, C13: 100n; C_0805_2012Metric_Pad1.18x1.45mm_HandSolder
C4, C5: 18pF; C_0603_1608Metric_Pad1.08x0.95mm_HandSolder
C6, C8: 1u; C_0805_2012Metric_Pad1.18x1.45mm_HandSolder
C11: 1u; C_1206_3216Metric_Pad1.33x1.80mm_HandSolder
D1, D2: BAT54S; SOT-23
H1, H2, H3, H4: MountingHole; MountingHole_2.2mm_M2_ISO7380
J1: Conn_01x06_Male; PinHeader_2x03_P2.54mm_Vertical
J2: USB_B_Micro; USB_Micro-B_Amphenol_10118194_Horizontal
J3: Conn_01x03_Male; PinHeader_1x03_P2.54mm_Vertical
J4: Conn_01x12; Flex_Tape_12x0.635
J5: Conn_01x02_Male; PinHeader_1x02_P2.54mm_Vertical
Q1: LGE2300; SOT-23
Q2: IRLML6402; SOT-23
Q3: BC817; SOT-23
R1, R2, R3: 100R; R_0603_1608Metric_Pad0.98x0.95mm_HandSolder
R4, R9, R12, R14: 10k; R_0603_1608Metric_Pad0.98x0.95mm_HandSolder
R5, R6, R7: 75k; R_0603_1608Metric_Pad0.98x0.95mm_HandSolder
R8: 1k; R_0603_1608Metric_Pad0.98x0.95mm_HandSolder
R10: 10R; R_0603_1608Metric_Pad0.98x0.95mm_HandSolder
R11: 3k; R_0603_1608Metric_Pad0.98x0.95mm_HandSolder
R13: 680k; R_0805_2012Metric_Pad1.20x1.40mm_HandSolder
SW1, SW2: TSS02-35; SW_SPST_TSS02-035NT
TP1, TP2, TP3, TP4, TP5, TP6, TP7, TP8: TestPoint; TestPoint_Pad_1.5x1.5mm
U1: STM32L051K6Tx; LQFP-32_7x7mm_P0.8mm
U2: AP2121N-3.3; SOT-23
U3, U4: 74LVC1G125; SOT-23-5_HandSoldering
U5: TP4054-42; SOT-23-5_HandSoldering
Y1: Crystal; Crystal_SMD_3215-2Pin_3.2x1.5mm

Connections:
+5V: C11.1, J2.1 (VBUS), U5.4 (VCC)
+BATT: C6.1, J5.2, Q2.2 (S), R5.1, U2.3 (VI), U5.3 (BAT)
/A_BAT: R6.2, R7.1, U1.6 (PA0)
/A_BAT_EN: R1.1, U1.8 (PA2)
/BAT_CH: R13.1, U1.7 (PA1), U5.1 (CHRG)
/LCD_BLK: R8.1, U1.12 (PA6)
/LCD_CS: J4.8, U1.14 (PB0)
/LCD_DC: J4.7, U1.10 (PA4)
/LCD_RST: J4.11, U1.15 (PB1)
/LCD_SCK: J4.9, U1.11 (PA5)
/LCD_SDA: J4.10, U1.13 (PA7)
/NRST: J1.5, U1.4 (NRST)
/PA3: TP5.1, U1.9 (PA3)
/PA8: TP6.1, U1.18 (PA8)
/PA11: TP7.1, U1.21 (PA11)
/PA12: TP8.1, U1.22 (PA12)
/PB4: TP1.1, U1.27 (PB4)
/PB5: TP2.1, U1.28 (PB5)
/PB6: TP3.1, U1.29 (PB6)
/PB7: TP4.1, U1.30 (PB7)
/RTC_OSC_IN: C5.1, U1.2 (PC14), Y1.2
/RTC_OSC_OUT: C4.1, U1.3 (PC15), Y1.1
/SWCLK: J1.2, U1.24 (PA14)
/SWDIO: J1.4, U1.23 (PA13)
/SW_1: C12.1, R12.2, SW1.2, U1.26 (PB3)
/SW_2: C13.1, R14.2, SW2.2, U1.25 (PA15)
/UART.RX: U1.20 (PA10), U4.4
/UART.TX: U1.19 (PA9), U3.2
GND: C1.2, C2.2, C3.2, C4.2, C5.2, C6.2, C7.2, C8.2, C9.2, C10.1, C11.2, C12.2, C13.2, D1.1, D2.1, J1.3, J2.5 (GND), J2.6 (Shield), J3.2, J4.1, J4.5, J4.6, J4.12, J5.1, Q1.2 (S), Q3.2 (E), R4.1, R7.2, R11.2, SW1.1, SW1.3, SW1.4, SW2.1, SW2.3, SW2.4, U1.16 (VSS), U1.31 (BOOT0), U1.32 (VSS), U2.1 (GND), U3.1, U3.3 (GND), U4.1, U4.3 (GND), U5.2 (GND)
unnamed: D1.3, R3.2, R4.2, U3.4
unnamed: D2.3, R2.2, U4.2
unnamed: J3.1, R2.1
unnamed: J3.3, R3.1
unnamed: J4.2, R10.2
unnamed: Q1.1 (G), R1.2
unnamed: Q1.3 (D), Q2.1 (G), R5.2
unnamed: Q2.3 (D), R6.1
unnamed: Q3.1 (B), R8.2, R9.2
unnamed: Q3.3 (C), R10.1
unnamed: R11.1, U5.5 (PROG)
VCC: C1.1, C2.1, C3.1, C7.1, C8.1, C9.1, C10.2, D1.2, D2.2, J1.1, J4.3, J4.4, R9.1, R12.1, R13.2, R14.1, U1.1 (VDD), U1.5 (VDDA), U1.17 (VDD), U2.2 (VO), U3.5 (VCC), U4.5 (VCC)

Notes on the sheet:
VCC = 3.3V (Vcc symbol used instead of +3.3V symbol because of connection errors with U3)
BATTERY CELL

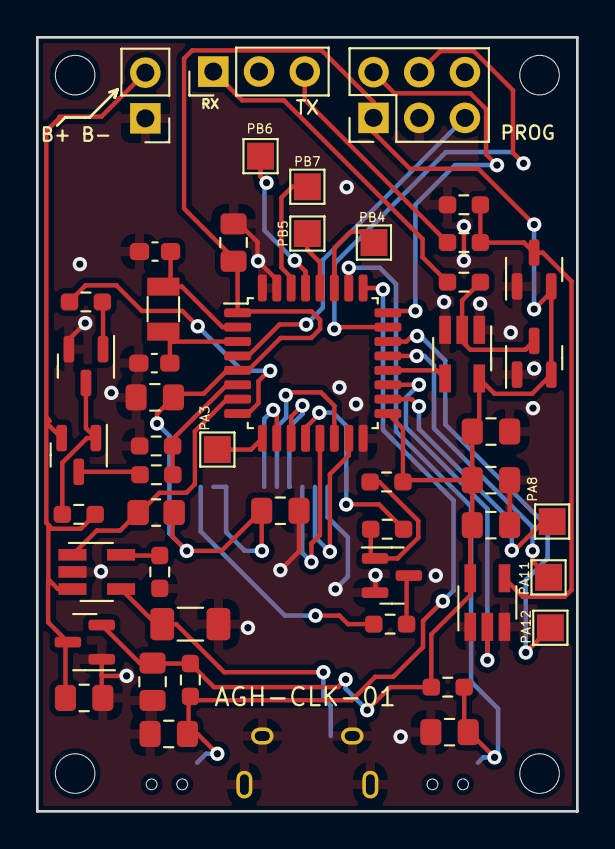
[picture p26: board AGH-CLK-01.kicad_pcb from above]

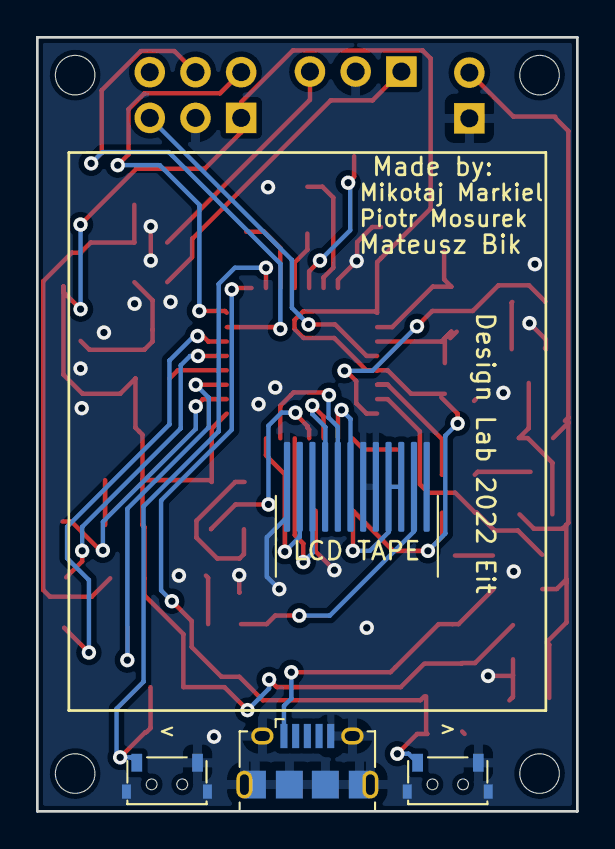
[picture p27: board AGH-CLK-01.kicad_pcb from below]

Board: 2 copper layers, 30.0 x 43.0 mm, 57 parts (4 on the bottom side), 41 nets.

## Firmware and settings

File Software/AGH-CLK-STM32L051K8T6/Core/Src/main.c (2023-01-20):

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
/* Includes ------------------------------------------------------------------*/
#include "main.h"

/* USER CODE BEGIN Includes */
#include "lcd.h"
#include <math.h>
#include <stdio.h>
/* USER CODE END Includes */

/* USER CODE BEGIN PTD */
typedef struct
{
	UG_COLOR s_pri;
	UG_COLOR s_sec;
	UG_COLOR m_pri;
	UG_COLOR m_sec;
	UG_COLOR h_pri;
	UG_COLOR h_sec;
	UG_COLOR t_dig;
	UG_COLOR d_dig;
} COLOR_T;
/* USER CODE END PTD */

ADC_HandleTypeDef hadc;

RTC_HandleTypeDef hrtc;

SPI_HandleTypeDef hspi1;
DMA_HandleTypeDef hdma_spi1_tx;
DMA_HandleTypeDef hdma_spi1_rx;

UART_HandleTypeDef huart1;

/* USER CODE BEGIN PV */
WATCH_HAND_T watchHand[3][60];
RTC_TimeTypeDef time;
RTC_DateTypeDef date;
COLOR_T color;
uint8_t reloadCol;
KEYBOARD_T keyboard;
uint32_t measBat;
uint8_t measRequest;
MODE_T mode;

/* USER CODE END PV */

void SystemClock_Config(void);
static void MX_GPIO_Init(void);
static void MX_DMA_Init(void);
static void MX_ADC_Init(void);
static void MX_RTC_Init(void);
static void MX_SPI1_Init(void);
static void MX_USART1_UART_Init(void);
/* USER CODE BEGIN PFP */

//Display
void DrawHand(WATCH_HAND_T* h, uint16_t col);
void SetHandDisplay(WATCH_HAND_T* h, uint8_t pos, uint8_t cnt, uint16_t primCol, uint16_t secCol);
void RefreshClock();

//ADC
void GetBatteryMeas(uint32_t * meas, uint8_t *cond);

//Keyboard
uint8_t KeyPressed(uint8_t* key);
uint8_t KeyHolded(uint32_t* key, uint32_t time);
uint8_t KeysHolded(uint32_t time);

//RTC
void SetTimeDate();

//MISC
void InitHandsCoords();
void ChangeColor(UG_COLOR s_pri, UG_COLOR s_sec, UG_COLOR m_pri, UG_COLOR m_sec, UG_COLOR h_pri, UG_COLOR h_sec, UG_COLOR t_dig, UG_COLOR d_dig);
void SetColor();
void CheckRegularState();

/* USER CODE END PFP */

/**
  * @brief  The application entry point.
  * @retval int
  */
int main(void)
{
  /* MCU Configuration--------------------------------------------------------*/

  /* Reset of all peripherals, Initializes the Flash interface and the Systick. */
  HAL_Init();

  /* Configure the system clock */
  SystemClock_Config();

  /* Initialize all configured peripherals */
  MX_GPIO_Init();
  MX_DMA_Init();
  MX_ADC_Init();
  MX_RTC_Init();
  MX_SPI1_Init();
  MX_USART1_UART_Init();
  /* USER CODE BEGIN 2 */
  measRequest = 1;
  LCD_init();
  HAL_ADCEx_Calibration_Start(&hadc, ADC_SINGLE_ENDED);
  InitHandsCoords();
  /* USER CODE END 2 */

  /* Infinite loop */
  /* USER CODE BEGIN WHILE */
  while (1)
  {
	  HAL_RTC_GetTime(&hrtc, &time, RTC_FORMAT_BIN);
	  HAL_RTC_GetDate(&hrtc, &date, RTC_FORMAT_BIN);
	  GetBatteryMeas(&measBat, &measRequest);
	  SetColor();
	  RefreshClock();
	  SetTimeDate();
	  CheckRegularState();

    /* USER CODE END WHILE */

    /* USER CODE BEGIN 3 */
  }
  /* USER CODE END 3 */
}

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
/* USER CODE BEGIN 4 */
void DrawHand(WATCH_HAND_T* h, uint16_t col)
{
	UG_DrawLine(h->x1, h->y1, h->x2, h->y2, col);
}

void SetHandDisplay(WATCH_HAND_T* h, uint8_t pos, uint8_t cnt, uint16_t primCol, uint16_t secCol)
{
	for(uint8_t i=60; i>60-cnt; i--)
	{
		uint16_t col = (pos+i) % 5 == 0 ? primCol : secCol;
		DrawHand(&h[(pos+i)%60], LCD_ColorOpacity(col, (60-i)>>1));
	}
}

void GetBatteryMeas(uint32_t * meas, uint8_t* cond)
{
	if (!*cond)
	{
		return;
	}
	HAL_GPIO_WritePin(A_BAT_EN_GPIO_Port, A_BAT_EN_Pin, 1);
	HAL_Delay(1);	//to avoid adc measure during transient state;
	HAL_ADC_Start(&hadc);
	HAL_ADC_PollForConversion(&hadc, HAL_MAX_DELAY);
	*meas = HAL_ADC_GetValue(&hadc) * VREF * ADC_V_DIV / ADC_DIV;
	HAL_GPIO_WritePin(A_BAT_EN_GPIO_Port, A_BAT_EN_Pin, 0);
	*cond = 0;
	return;
}

void InitHandsCoords()
{
	uint8_t i = 0, j = 0, z = 0;
	for(z=0; z<3; z++)
	{
		for(j=0; j<60; j++)
		{
			i = ((j % 5) == 0) ? 0 : 10;
			watchHand[z][j].x1 = 120 + (70+z*25)*sin((j%60)*2*M_PI/60);
			watchHand[z][j].y1 = 120 - (70+z*25)*cos((j%60)*2*M_PI/60);
			watchHand[z][j].x2 = 120 + (50+i+z*25)*sin((j%60)*2*M_PI/60);
			watchHand[z][j].y2 = 120 - (50+i+z*25)*cos((j%60)*2*M_PI/60);
		}
	}
}

void ChangeColor(UG_COLOR s_pri, UG_COLOR s_sec, UG_COLOR m_pri, UG_COLOR m_sec, UG_COLOR h_pri, UG_COLOR h_sec, UG_COLOR t_dig, UG_COLOR d_dig)
{
	color.s_pri = s_pri;
	color.s_sec = s_sec;
	color.m_pri = m_pri;
	color.m_sec = m_sec;
	color.h_pri = h_pri;
	color.h_sec = h_sec;
	color.t_dig = t_dig;
	color.d_dig = d_dig;
}

void SetColor()
{
	switch (mode)
	{
									   //sec_pri |sec_sec |min_pri |min_sec |hour_pri|hour_sec|time_dig|date_dig
		case regular:        ChangeColor(C_WHITE, C_BLUE,  C_WHITE, C_WHITE, C_WHITE, C_BLUE,  C_WHITE, C_WHITE); break;
		case reg_bat_low:    ChangeColor(C_WHITE, C_ORANGE,C_WHITE, C_WHITE, C_WHITE, C_ORANGE,C_WHITE, C_WHITE); break;
		case reg_discharged: ChangeColor(C_WHITE, C_RED,   C_WHITE, C_WHITE, C_WHITE, C_RED,   C_WHITE, C_WHITE); break;
		case reg_charging:   ChangeColor(C_WHITE, C_YELLOW,C_WHITE, C_WHITE, C_WHITE, C_YELLOW,C_WHITE, C_WHITE); break;
		case reg_bat_full:   ChangeColor(C_WHITE, C_GREEN, C_WHITE, C_WHITE, C_WHITE, C_GREEN, C_WHITE, C_WHITE); break;
		case set_hour:       ChangeColor(C_BLACK, C_BLACK, C_BLACK, C_BLACK, C_WHITE, C_WHITE, C_WHITE, C_BLACK); break;
		case set_minute:     ChangeColor(C_BLACK, C_BLACK, C_WHITE, C_WHITE, C_BLACK, C_BLACK, C_WHITE, C_BLACK); break;
		case set_second:     ChangeColor(C_WHITE, C_WHITE, C_BLACK, C_BLACK, C_BLACK, C_BLACK, C_WHITE, C_BLACK); break;
		case set_day:        ChangeColor(C_BLACK, C_BLACK, C_BLACK, C_BLACK, C_BLACK, C_BLACK, C_BLACK, C_WHITE); break;
		case set_month:      ChangeColor(C_BLACK, C_BLACK, C_BLACK, C_BLACK, C_BLACK, C_BLACK, C_BLACK, C_WHITE); break;
		case set_year:  	 ChangeColor(C_BLACK, C_BLACK, C_BLACK, C_BLACK, C_BLACK, C_BLACK, C_BLACK, C_WHITE); break;
	}
}

uint8_t KeyPressed(uint8_t* key)
{
	uint8_t t = *key;
	*key = 0;
	return t;
}

uint8_t KeyHolded(uint32_t* key, uint32_t time)
{
	uint8_t t = *key >= time ? 1 : 0;
	if (t) *key = 0;
	return t;
}

uint8_t KeysHolded(uint32_t time)
{
	static uint8_t t;
	t = 0;
	if(keyboard.l_hold >= time && keyboard.r_hold >= time)
	{
		keyboard.l_hold = 0;
		keyboard.r_hold = 0;
		t = 1;
	}
	return t;
}

void RefreshClock()
{
	static struct
	{
		uint8_t sec;
		uint8_t min;
		uint8_t hour;
		uint8_t day;
		uint8_t mth;
		uint8_t year;
	} change;

	static uint8_t hourPos;
	static RTC_TimeTypeDef time_old;
	static RTC_DateTypeDef date_old;
	static MODE_T mode_old;

	static char dateDisplay[9];
	static char timeDisplay[6];

	change.sec  = (time_old.Seconds == time.Seconds) ? 0 : 1;
	change.min  = (time_old.Minutes == time.Minutes) ? 0 : 1;
	change.hour = (time_old.Hours   == time.Hours)   ? 0 : 1;
	change.day  = (date_old.Date    == date.Date)    ? 0 : 1;
	change.mth  = (date_old.Month   == date.Month)   ? 0 : 1;
	change.year = (date_old.Year    == date.Year)    ? 0 : 1;

	if(mode_old != mode)
	{
		change.sec = 1;
		change.min = 1;
		change.hour = 1;
		change.day = 1;
		change.mth = 1;
		change.year = 1;
		mode_old = mode;
	}

	if (!(change.sec || change.min || change.hour || change.day || change.mth || change.year))
	{
		return;
	}

	hourPos = ((time.Hours%12)*5) + (time.Minutes/12);

	//fast reload - only one watch hand
	if (change.sec)
	{
		SetHandDisplay(watchHand[SEC], time.Seconds, 1, color.s_pri, color.s_sec);
	}
	if (change.min)
	{
		SetHandDisplay(watchHand[MIN], time.Minutes, 1, color.m_pri, color.m_sec);
	}
	if (change.hour)
	{
		SetHandDisplay(watchHand[HOUR], hourPos, 1, color.h_pri, color.h_sec);
	}

	if (change.min || change.hour)
	{
		sprintf(timeDisplay, "%02d:%02d", time.Hours, time.Minutes);
		LCD_PutStr(89, 95, timeDisplay, FONT_arial_25X28, LCD_ColorOpacity(color.t_dig, 7), C_BLACK);
	}
	if (change.day || change.mth || change.year)
	{
		sprintf(dateDisplay, "%02d.%02d.%02d", date.Date, date.Month, date.Year);
		LCD_PutStr(89, 130, dateDisplay, FONT_arial_16X18, LCD_ColorOpacity(color.d_dig, 5), C_BLACK);
	}

	//slow reload - rest of watch hands
	if (change.sec)
	{
		SetHandDisplay(watchHand[SEC], time.Seconds, 60, color.s_pri, color.s_sec);
	}
	if (change.min)
	{
		SetHandDisplay(watchHand[MIN], time.Minutes, 60, color.m_pri, color.m_sec);
	}
	if (change.hour)
	{
		SetHandDisplay(watchHand[HOUR], hourPos, 60, color.h_pri, color.h_sec);
	}

	time_old.Seconds = time.Seconds;
	time_old.Minutes = time.Minutes;
	time_old.Hours = time.Hours;
	date_old.Date = date.Date;
	date_old.Month = date.Month;
	date_old.Year = date.Year;

	return;
}

void SetTimeDate()
{
	static uint8_t* curr_p;
	static MODE_T mode_old;
	static uint8_t mod;
	static uint8_t setTimeFlag;
	static enum
	{
		hour,
		min,
		sec,
		day,
		month,
		year
	} num = hour;

	if (KeysHolded(100))
	{
		setTimeFlag = 1;
	}

	if (!setTimeFlag)
	{
		mode_old = mode;
		return;
	}

	switch(num)
	{
		case hour:  curr_p = &time.Hours;   mod = 24; break;
		case min:   curr_p = &time.Minutes; mod = 60; break;
		case sec:   curr_p = &time.Seconds; mod = 60; break;
		case day:   curr_p = &date.Date;    mod = 31; break;
		case month: curr_p = &date.Month;   mod = 12; break;
		case year:  curr_p = &date.Year;	mod = 99; break;
		default: curr_p = NULL;
	}

	if(*curr_p == 0)
	{
		*curr_p = mod;
	}
	*curr_p = (*curr_p + KeyPressed(&keyboard.l_press) - KeyPressed(&keyboard.r_press)) % mod;

	HAL_RTC_SetTime(&hrtc, &time, RTC_FORMAT_BIN);
	HAL_RTC_SetDate(&hrtc, &date, RTC_FORMAT_BIN);

	if (!KeysHolded(50))
	{
		mode = set_hour + num;
		return;
	}
	UG_DrawLine(89, 150, 151, 150, C_BLACK);
	if (num == year)
	{
		num = 0;
		setTimeFlag = 0;
		mode = mode_old;
		return;
	}
	else
	{
		num++;
		mode = set_hour + num;
		if (mode == set_day)
		{
			UG_DrawLine(89, 150, 107, 150, C_WHITE);
		}
		else if (mode == set_month)
		{
			UG_DrawLine(111, 150, 129, 150, C_WHITE);
		}
		else if (mode == set_year)
		{
			UG_DrawLine(131, 150, 151, 150, C_WHITE);
		}
		return;
	}
}

void CheckRegularState()
{
	static uint8_t isCharging;

	if (mode > reg_bat_full)
		return;
	isCharging = HAL_GPIO_ReadPin(BAT_CH_GPIO_Port, BAT_CH_Pin);

	if(isCharging == BATTERY_IS_CHARGING && measBat >= BATTERY_LIMIT_GREEN)
	{
		mode = reg_bat_full;
	}
	else if(isCharging == BATTERY_IS_CHARGING && measBat <  BATTERY_LIMIT_GREEN)
	{
		mode = reg_charging;
	}
	else if(isCharging != BATTERY_IS_CHARGING && measBat <  BATTERY_LIMIT_RED)
	{
		mode = reg_discharged;
	}
	else if(isCharging != BATTERY_IS_CHARGING && measBat <  BATTERY_LIMIT_ORANGE)
	{
		mode = reg_bat_low;
	}
	else
	{
		mode = regular;
	}
}

/* USER CODE END 4 */
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


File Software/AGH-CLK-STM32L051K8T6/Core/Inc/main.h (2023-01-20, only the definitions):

#define A_BAT_Pin GPIO_PIN_0
#define A_BAT_GPIO_Port GPIOA
#define BAT_CH_Pin GPIO_PIN_1
#define BAT_CH_GPIO_Port GPIOA
#define A_BAT_EN_Pin GPIO_PIN_2
#define A_BAT_EN_GPIO_Port GPIOA
#define LCD_DC_Pin GPIO_PIN_4
#define LCD_DC_GPIO_Port GPIOA
#define LCD_SCK_Pin GPIO_PIN_5
#define LCD_SCK_GPIO_Port GPIOA
#define LCD_BLK_Pin GPIO_PIN_6
#define LCD_BLK_GPIO_Port GPIOA
#define LCD_SDA_Pin GPIO_PIN_7
#define LCD_SDA_GPIO_Port GPIOA
#define LCD_CS_Pin GPIO_PIN_0
#define LCD_CS_GPIO_Port GPIOB
#define LCD_RST_Pin GPIO_PIN_1
#define LCD_RST_GPIO_Port GPIOB
#define SW2_Pin GPIO_PIN_15
#define SW2_GPIO_Port GPIOA
#define SW1_Pin GPIO_PIN_3
#define SW1_GPIO_Port GPIOB
#define VREF					3300	// mV
#define ADC_DIV					4096	// resolution
#define ADC_V_DIV				2		// R/R
#define BATTERY_MEAS_DELAY		10000	// ms
#define BATTERY_LIMIT_GREEN		4000	// mV
#define BATTERY_LIMIT_ORANGE	3750	// mV
#define BATTERY_LIMIT_RED		3700	// mV
#define BATTERY_IS_CHARGING		0

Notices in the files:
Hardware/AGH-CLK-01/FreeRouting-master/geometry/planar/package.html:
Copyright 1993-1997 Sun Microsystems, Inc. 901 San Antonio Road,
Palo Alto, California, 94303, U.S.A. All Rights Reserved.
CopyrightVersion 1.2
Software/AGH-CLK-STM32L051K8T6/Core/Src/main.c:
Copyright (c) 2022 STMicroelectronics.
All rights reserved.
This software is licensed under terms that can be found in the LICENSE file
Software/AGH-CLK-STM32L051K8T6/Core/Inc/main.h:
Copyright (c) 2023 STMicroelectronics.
